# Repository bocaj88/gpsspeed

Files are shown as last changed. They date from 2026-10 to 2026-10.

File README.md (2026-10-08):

# GPSSpeed: a GPS replacement for the PerfectPass paddlewheel

**A small board that reads GPS speed and feeds it to PerfectPass as if it were the paddlewheel.**
Built for, and being tested on, our **2008 MasterCraft X2**. Everything is open: schematic, PCB,
firmware, and the notes on what didn't work along the way.

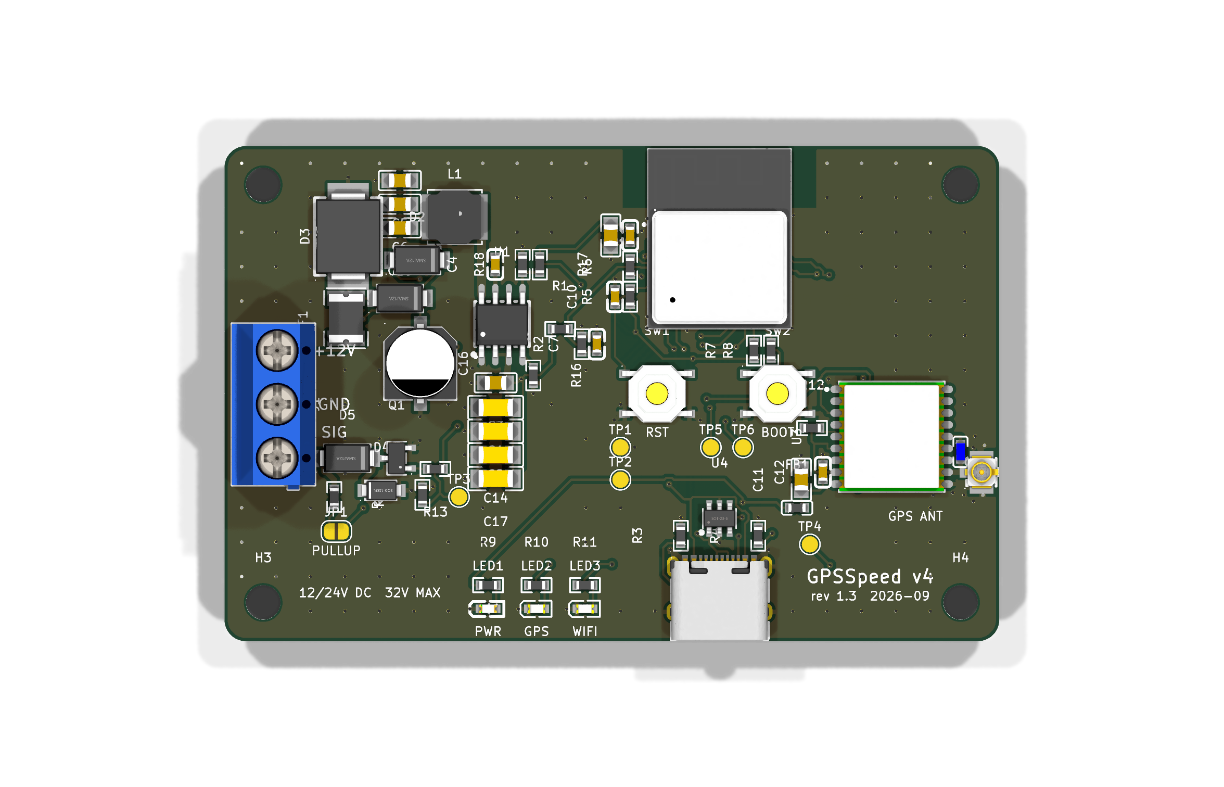
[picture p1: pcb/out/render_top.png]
GPSSpeed v4 rev 1.3


## The problem

**The paddlewheel speed sensor on our X2 went bad, and replacement sensors aren't sold anymore.**
Without it, PerfectPass has no speed to hold, so the speed control on the boat was dead.

PerfectPass holds a tow boat at a set speed by reading the boat's **paddlewheel speed sensor**: a
small wheel under the hull that spins in the water and sends one pulse per fraction of a turn.
On our X2 that sensor is part of an Airmar DST800-style triducer (speed, depth, temperature). It
sends about 20,000 pulses per nautical mile, and PerfectPass turns the pulse rate into speed.

Paddlewheels are the weak link:

- **They foul.** Weed, a fishing line, or a little growth, and the wheel drags or stops. PerfectPass
  then sees the wrong speed (or none) and drives the throttle accordingly.
- **You can't buy a replacement.** The DST800 is now an Airmar *legacy* product. Ours failed, and
  there was nothing to swap in.
- **They're never quite right.** Paddlewheel speed depends on the wheel, the hull, and how clean it
  is, so the dash and the real speed drift apart.

GPS speed doesn't have any of these problems. So the idea is simple: **read speed from GPS, and
generate the same pulse train the paddlewheel would**, on the same wire. PerfectPass doesn't know
the difference, and nothing else on the boat changes.

## How it works

```
 GPS antenna ──► ATGM336H GPS ──► ESP32-C3 ──► protected low-side switch ──► SIGNAL ──► PerfectPass
                 (10 Hz speed)    (pulse rate =      (open-drain, like the
                                   MPH × 4.42 Hz)     paddlewheel's own output)
 Boat 12 V ──► protection + buck ──► 3.3 V
```

- **Output:** a 50 % square wave whose frequency is proportional to speed: **4.42 Hz per MPH** by
  default (about 22 Hz at 5 MPH, 133 Hz at 30 MPH), calibrated from the phone app. It's generated by
  the ESP32's LEDC hardware timer from the 40 MHz crystal, so it's exact (worst-case 0.02 % error)
  and nothing in software can stretch a pulse.
- **No GPS fix yet:** it holds a steady 5 MPH. It never sweeps, because PerfectPass chases a sweep.
- **Lag compensation:** a small predictor projects speed ~0.3 s ahead from GPS acceleration, so
  PerfectPass isn't correcting late and hunting.
- **Phone app, no app install:** for 2 minutes after power-up the board runs its own WiFi network
  (`GPSSpeed-XXXX`, open). Join it and the app pops up: live speed, satellites, a self-test that
  steps through set speeds, a dash calibration table, settings, and **firmware updates over WiFi**.
  Then the radio turns itself off for the rest of the day on the water. It's also at
  `http://gpsspeed.local` while connected.
- **Wiring:** three screw terminals: **+12 V, GND, SIGNAL**.

## Status (October 2026)

| | |
|---|---|
| Hardware | **Rev 1.3**, 5 boards assembled by JLCPCB. Three external EE review rounds (summarized in [docs/04-design-reviews.md](docs/04-design-reviews.md)). |
| Bench-tested | Power, USB, GPS (13–16 satellites, fix indoors), antenna power, battery sense, phone app, **OTA update from an iPhone**. See [docs/05-bring-up.md](docs/05-bring-up.md). |
| Not yet tested | 12 V boat power, the output against a real PerfectPass input, on-water calibration. |
| Firmware | 4.0.8 (`firmware/gpsspeed_v4/bin/`) |

This is a prototype that hasn't run on the water yet. Read [the safety note](#safety) before
connecting it to a boat.

## 4 spare boards

We built 5 and need 1. **The other 4 are available** to anyone who wants to try this on their own
PerfectPass boat. They're fully assembled and flashed: you add an antenna and three wires. Reply in
the forum thread or open an issue on this repo.

## What you need to install one

The board, a GPS antenna, and three wires to the boat. The full list, with where to get each
cable and adapter, is in **[docs/06-wiring-and-cables.md](docs/06-wiring-and-cables.md)**.

## Repo map

| Path | What's there |
|---|---|
| [docs/](docs/) | The research: problem, history, design, reviews, bring-up, wiring, costs |
| [pcb/](pcb/) | KiCad 10 project, generator scripts, JLCPCB order files, renders. Start with [pcb/README.md](pcb/README.md) |
| [firmware/gpsspeed_v4/](firmware/gpsspeed_v4/) | ESP32-C3 firmware (Arduino core 3.3), prebuilt `.bin` images |
| [firmware/test/](firmware/test/) | Host-side tests of the pulse-generation and calibration math |
| [legacy/arduino-uno/](legacy/arduino-uno/) | The earlier Arduino Uno + perfboard builds (v1–v3) |
| [docs/forum-post.md](docs/forum-post.md) | The short version, for forums |

## Safety

This board changes what your speed control believes the boat is doing, and PerfectPass controls the
throttle. Test it at idle and low speed first. Keep a hand on the throttle, and know how to
disengage PerfectPass. Compare the dash against a phone GPS app before trusting it with a rider
behind the boat. Use it at your own risk; see the license.

## License

MIT (see [LICENSE](LICENSE)) for the firmware, scripts, docs and hardware design files.

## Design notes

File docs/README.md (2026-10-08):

# Research and notes

Read in order. Each page stands on its own.

1. [Background: PerfectPass and the paddlewheel](01-background.md): the problem, the signal, the math
2. [History: the Arduino Uno builds](02-history-uno-builds.md): v1 to v3, and the 21 MPH wall
3. [The v4 board](03-v4-board-design.md): design decisions for the ESP32-C3 board
4. [Design reviews](04-design-reviews.md): three EE review rounds and what changed
5. [Bring-up log](05-bring-up.md): first power-up results and firmware fixes
6. [Wiring, cables and adapters](06-wiring-and-cables.md): what you need to install one
7. [Cost and ordering](07-cost-and-ordering.md): what 5 boards cost and how to order them

Also: [TODO](TODO.md) · [Forum post](forum-post.md)

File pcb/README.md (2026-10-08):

# GPSSpeed v4 — ESP32-C3 board

GPS → paddlewheel pulse emulator for PerfectPass, rebuilt as a JLCPCB-assembled
board. Replaces the Uno + perfboard hat.

| | |
|---|---|
| Size | 72 × 46 mm, 2 layers, 1.6 mm, 4× M3 holes |
| Power | **12/24 V DC nominal, 32 V continuous max.** 60 V polyfuse → 1.5 kW bidirectional TVS (±58 V clamp) → 100 V reverse-polarity Schottky → 22 µF/100 V bulk + 4 × 2.2 µF/100 V → LMR38010 buck (80 V operating, 85 V abs max). USB-C on the bench. |
| Brain | ESP32-C3-MINI-1-H4 (WiFi boot window, OTA updates; 105 °C part) |
| GPS | ATGM336H-5N31 (GPS+BeiDou, 10 Hz), u.FL for the existing active antenna |
| Output | ZXMS6004FF self-protected low-side switch (60 V, current limit, thermal shutdown, active clamp) behind a series Schottky (swapped +12 V/GND can't back-drive the dash), 33 V TVS on the drain; survives SIGNAL wired to +12 V; optional pull-up to the input rail via JP1 (ships **open**) |
| Connector | J1 screw terminal: **1 = +12 V, 2 = GND, 3 = SIGNAL** (wires enter from the board edge) |
| LEDs | PWR (red), GPS (green), WIFI (green) |

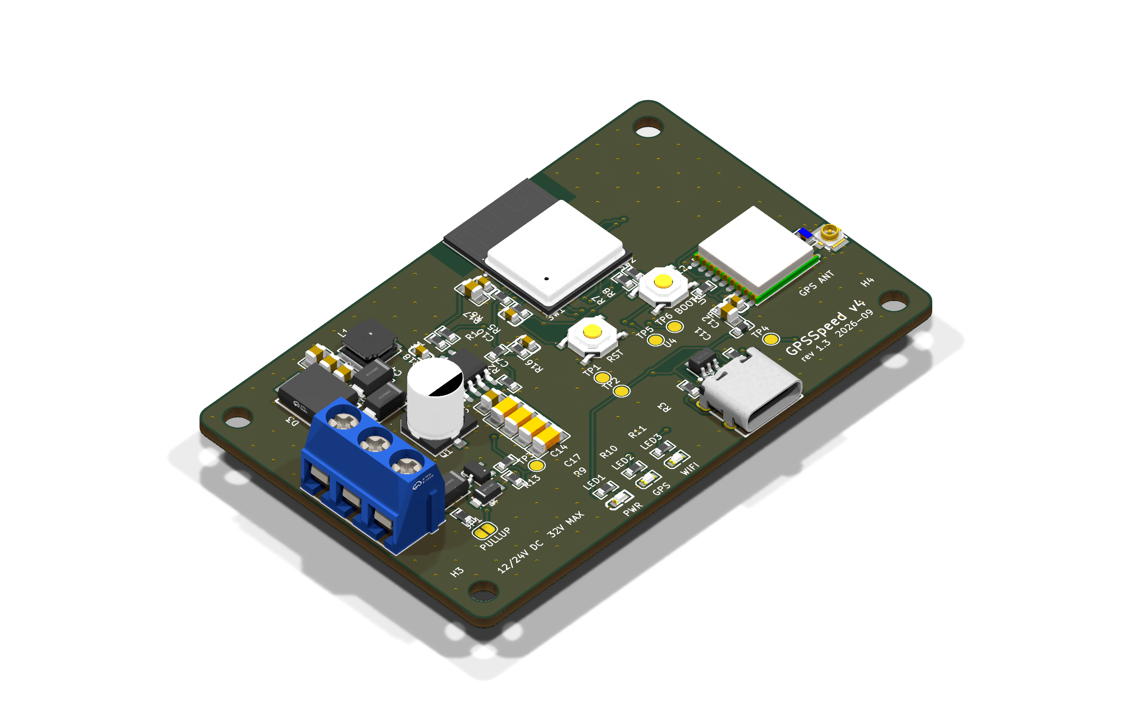
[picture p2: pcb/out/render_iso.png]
top


## Rev 1.3 — third EE review (independent)

| Review item | Change |
|---|---|
| Stop-ship: SIGNAL wired to +12 V shorts the supply through D5 and a bare 2N7002K the first time Q1 turns on | Q1 → **ZXMS6004FF** IntelliFET: current limit 0.7–1.7 A, thermal shutdown with auto-restart, short-circuit protected to V<sub>DS</sub> 36 V. Specified for 3.3 V logic (V<sub>IH</sub> 3 V, 0.6 Ω max at 3 V) |
| D4 (53 V max clamp) vs Q1 (60 V) margin thin | Q1's own active clamp is 60–70 V / 90 mJ, so a spike past D4 is absorbed by design instead of avalanching a bare MOSFET |
| (follows from the above) | SIGNAL_OUT / SIGNAL_DRAIN routed at **0.5 mm** for the 1.7 A fault current |

Bench items from that review (not schematic errors): output-low level with D5 in series against the real
PerfectPass input; USB-only startup at ~4.6 V into the buck. JP1 stays open on 24 V boats.
Q1 switching: ~15 µs on / ~60 µs off. Constant edge delays leave the output frequency unchanged; duty
shifts by ~1 % at 60 MPH.

## Rev 1.2 — second EE review (reviewed the native KiCad files)

| Review item | Change |
|---|---|
| C16 only 63 V against a 58 V clamp | **22 µF / 100 V**, same series and 6.3 × 7.7 can (RV100V22M6X8) |
| Battery-sense pin reaches 3.6 V at the clamp | R1 150k → **220k** (×23): 32 V reads 1.4 V, the 58 V clamp 2.5 V. Firmware **4.0.2** |
| Input ceramics borderline after DC-bias derating | **4th 2.2 µF / 100 V** (C17) |
| 24 V pull-up would forward-bias D5 and make D4 clamp continuously | Q1 → **2N7002K 60 V**, D4 → **SMF33A** (33 V standoff, 53 V clamp < 60 V) |
| Buck exposed pad: one full paste opening, no thermal path | Paste split into **4 windows (60 %)**; **2 tented GND vias** just past the GND-pin end of the pad; pad tied solid into the pour |
| (found while re-checking) | Two u.FL stitching vias overlapped fanout vias (drill-to-drill). Fanout now avoids existing vias, and drill spacing fails the build |

Not changed: L1 stays where it is (SW node ~8.7 mm total; moving it means relocating D2 in the
packed input corner — the reviewer rated it optional for prototypes). D2 stays an SS310: it has
to block up to ~53 V when USB and boat power are both connected, and USB power is bench-only.

## Rev 1.1 — changes from the external EE review

| Review item | Change |
|---|---|
| "12–24 V" label wrong (old TVS conducted ~20 V) | Input re-rated; silk now reads **12/24V DC 32V MAX** |
| TVS + PTC too close to the AP63203's 35 V abs max | Buck → **LMR38010** (80 V / 85 V abs), TVS → **SMCJ36CA** 1.5 kW bidirectional, PTC → 60 V, D1/D2 → **SS310** 100 V, input ceramics → 100 V, + **47 µF/63 V** bulk |
| L2's 1.2 GHz SRF below GPS L1 | L2 → **Murata LQW18AN27NG** wirewound, SRF 3.7 GHz |
| SIGNAL back-drive on reverse wiring | **D5 SS310 in series** at J1 pin 3 (chosen over a resistor so a stiff head-unit pull-up can't break the low level; adds ~0.3 V) |
| Open via-in-pad under the ESP32 | Removed; also stripped 4 open vias JLC's footprint put in the buck's exposed pad |
| Buck loop / u.FL grounding | Hand-routed C3–VIN–GND loop (~2 mm), SW straight into L1, FB on the quiet side; 8 stitching vias around the u.FL |

Not changed (reviewed and accepted): USB diode-OR (verify startup during WiFi TX on the bench),
reboot on very deep crank dips (firmware ignores brownouts for rollback), SMF15A on the drain
(24.4 V clamp < Q1's 30 V).

**Potting:** keep resin off the ESP32 antenna end (top edge) — resin detunes the PCB antenna.
Leave an air pocket there, or pot only the lower two-thirds of the board.

## What fixes the old problems

- **21 MPH cliff:** gone. The square wave comes from the LEDC hardware peripheral off
  the 40 MHz crystal; no software can stretch it. Measured on the real firmware code:
  worst frequency error **0.02 %** across 1–60 MPH (the Uno drifted up to 2.5 % fast
  at 30 MPH from its 128 µs rounding).
- **One serial port:** the GPS has its own hardware UART; USB-C serial is always free.
- **Tuning at the dock with a laptop:** everything is edited from your phone.

## Files

```
pcb/
  gpsspeed.kicad_pro / .kicad_sch / .kicad_pcb   open in KiCad 10
  gpsspeed.kicad_dru      two scoped DRC exceptions (explained inside)
  lib/                    exact JLC footprints/symbols/3D (easyeda2kicad)
  gen/                    the generators -- design.py is the netlist source of truth
  out/jlcpcb/             gerbers.zip, bom_jlcpcb.csv, cpl_jlcpcb.csv   <- upload these
  out/                    schematic PDF, assembly PDF, STEP, renders
firmware/gpsspeed_v4/     ESP32-C3 firmware; bin/ has prebuilt images
firmware/test/            host-side tests of the pulse + calibration code
```

## Ordering at JLCPCB

1. **PCB:** upload `out/jlcpcb/gerbers.zip`. Defaults are right: 2 layers, 1.6 mm,
   HASL lead-free, green. Qty 5 (the minimum).
2. **PCB Assembly:** on, *Standard*, *Top side*, qty **5**. (Economic won't take
   the ESP32 module -- JLC flags every ESP32-C3-MINI-1 "Standard PCBA only".)
3. Upload `bom_jlcpcb.csv` and `cpl_jlcpcb.csv`.
4. In the **parts review**, every line should match an LCSC number. J1 (screw
   terminal) is through-hole; if Economic won't place it, untick it and solder its
   3 pins by hand.
5. In the **placement preview**, check polarity/pin-1 on: D1–D5, C16 (+), LED1–3, U1–U4, Q1,
   J2, J3. Footprints came from JLC's own library, so rotations should already
   match, but this is the one step a human should eyeball.

Rev 1.1 quote (2026-09-26), for reference: 5 assembled boards $162.84, + UPS ~$37 + US
customs duty ~$61 (JLC collects it up front with DDP shipping) − $10 coupon ≈ $251.

## Bring-up

1. **Before power:** meter +12 V to GND on J1 — must not beep.
2. **USB-C only first.** PWR LED on, TP2 = 3.3 V.
3. Flash once over USB-C:
   ```
   esptool.py --chip esp32c3 write_flash 0x0 firmware/gpsspeed_v4/bin/gpsspeed_v4-4.0.8-usb-full.bin
   ```
   (or `arduino-cli upload` — build command is in `gpsspeed_v4.ino`). If it won't
   connect, hold **BOOT**, tap **RST**, release BOOT.
4. Serial monitor at 115200: expect `chars:` climbing and `ant:OK` once the antenna
   is on. `ant:OPEN` = antenna not connected / passive; `ant:SHORT` = cable fault.
5. Plug in the antenna, go outside, wait for the GPS LED to go solid.
6. **Then** wire the boat: +12 V, GND, SIGNAL to the paddlewheel signal line.

## Using it on the boat

- Power on → join WiFi **`GPSSpeed-XXXX`** (open, no password; XXXX is fixed per board) → the page pops up, tap **Done** → later just open **http://gpsspeed.local**
  (Safari; a captive-portal sheet may open on its own).
- The access point lives **2 minutes** after power-on, extends while your phone is
  connected, then turns the radio off. To get back in: cycle power.
- **Calibrate once:** tap *Self-test*, and at each step type what the dash shows into
  *Dash shows* → *Save point*. One pass gets the dash within ~0.01 MPH at the
  calibrated speeds (tested against a simulated nonlinear dash).
- While GPS is searching the output holds a steady **5 MPH** (never sweeps).
- **Firmware updates:** *Firmware → Upload* the `-ota.bin`. A bad build that
  crash-loops rolls back to the previous one automatically; brownouts from engine
  cranking do not count as crashes.

## Things I could not verify without hardware

- **CASIC config commands** (`$PCAS01/02/03`) follow ZhongKe's documented format. If
  the module ignores one, the firmware still works at its defaults (9600 baud, 1 Hz)
  — the web UI shows the actual baud/rate it achieved.
- **Default Hz/MPH is 4.42**, the Uno's *effective* constant at 15–26 MPH. Expect to
  run the self-test once.
- **Active antenna assumed** (GT-U7 kits ship with one). For a passive antenna,
  remove L2.
- **Wiring polarity:** the board survives +12 V/GND swapped (D5 keeps the swap from
  back-driving the dash input) and SIGNAL wired to +12 V (Q1 current-limits and thermal-cycles).
  Still meter it before powering.
- **JP1 on 24 V boats:** leave it open. Bridged at 28.8 V, R15 (0603) runs near its 0.1 W
  rating; the dash's own pull-up is the normal case anyway.

## Regenerating

```
cd pcb/gen
~/Applications/KiCad/KiCad.app/Contents/Frameworks/Python.framework/Versions/3.9/bin/python3 gen_sch.py
~/Applications/KiCad/KiCad.app/Contents/Frameworks/Python.framework/Versions/3.9/bin/python3 build.py   # place, route, pour, DRC
python3 gen_outputs.py                                                                                  # JLC files
```
`build.py` needs Freerouting (`~/Applications/freerouting`) and Java ≥ 25
(`brew install openjdk`). Edit `design.py` for circuit changes, `gen_pcb.py` for
placement.

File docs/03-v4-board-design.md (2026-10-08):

# 3. The v4 board (ESP32-C3)

The full hardware write-up, including the bring-up checklist, is [pcb/README.md](../pcb/README.md).
This page covers the main decisions and the reasons behind them.

| | |
|---|---|
| Size | 72 × 46 mm, 2 layers, 4 × M3 holes |
| MCU | ESP32-C3-MINI-1-H4 (WiFi, native USB, 105 °C rated) |
| GPS | ATGM336H-5N31 (GPS + BeiDou, 10 Hz), u.FL for an external **active** antenna |
| Power in | 12/24 V nominal, **32 V continuous max**; USB-C on the bench |
| Output | ZXMS6004FF protected low-side switch behind a series Schottky. Open-drain, like the paddlewheel |
| Connector | J1 screw terminal: **1 = +12 V, 2 = GND, 3 = SIGNAL** |
| LEDs | PWR (red), GPS (green), WIFI (green) |

## Decisions

**ESP32-C3 instead of another AVR or an RP2040.** WiFi comes free on the chip, and iOS can't use Web
Bluetooth, so a web page served by the board beats BLE plus a custom app. The C3 also has a
separate hardware UART for the GPS and native USB for flashing and logs. That solves the Uno's
one-serial-port problem outright.

**Hardware pulse generation.** The output comes from the LEDC peripheral, clocked from the 40 MHz
crystal. The Arduino `ledc` API only accepts whole hertz (0.23 MPH steps), so the firmware writes
the fractional clock divider directly (`div = 625000 / f`). Host tests show **≤ 0.02 % frequency
error** from 1 to 60 MPH.

**GPS module soldered to the board.** The ATGM336H is configured with CASIC `$PCAS` commands (it
doesn't speak u-blox UBX). The firmware auto-detects the baud rate and switches the module to
115200 baud and 10 Hz. That was confirmed on the first board.

**Power: built for a hostile boat harness.**
60 V polyfuse → 1.5 kW bidirectional TVS (SMCJ36CA, ≈ ±58 V clamp) → 100 V reverse-polarity Schottky
→ 22 µF/100 V bulk + 4 × 2.2 µF/100 V → TI LMR38010 buck (80 V operating, 85 V abs max) → 3.3 V.
USB-C also feeds the buck through a second diode, so the board runs from either source.

**Output stage: survives miswiring.**
- A **ZXMS6004FF IntelliFET** (60 V, current limit 0.7–1.7 A, thermal shutdown, 60–70 V active
  clamp) pulls SIGNAL low. If SIGNAL is wired to +12 V by mistake, it current-limits and cycles
  instead of burning out.
- A **series Schottky (D5)** stops a swapped +12 V/GND from back-driving the dash input through the
  switch. It adds about 0.3 V to the low level, much like a real Hall-effect sensor.
- A **33 V TVS** clamps the drain, so a 24 V pull-up is fine.
- An optional on-board **4.7 k pull-up** (JP1, ships open) covers dashes that don't supply one.

**WiFi boot window.** The access point runs for 2 minutes after power-up, extends while a phone is
connected, then shuts off. Firmware updates over WiFi verify the image, and a build that
crash-loops rolls back automatically. Brownout resets from engine cranking don't count as crashes.

**Potting.** Keep resin off the ESP32 antenna end (top edge), or pot only the lower two-thirds:
resin detunes the PCB antenna.

## How the board was generated

The schematic and PCB come from Python scripts. `pcb/gen/design.py` is the single netlist source.
Footprints and 3D models are pulled from JLC's own library (easyeda2kicad), routing is done by
Freerouting, then ground pours and stitching are added. Every build must pass KiCad DRC, ERC and
schematic parity, and drill spacing is a hard error. See *Regenerating* in
[pcb/README.md](../pcb/README.md).

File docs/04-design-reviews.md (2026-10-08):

# 4. Design reviews

The board went through three external electrical-engineering reviews before it was ordered. Each
round's findings and what changed are below; the per-revision tables are also in
[pcb/README.md](../pcb/README.md).

## Round 1: rev 1.0 → 1.1

Reviewer's verdict: fine on a bench supply, but not ready for an unsuppressed marine electrical
system.

| Finding | Change |
|---|---|
| The "12–24 V" label was wrong: the old SMBJ18A TVS starts conducting around 20 V | Input re-rated; silkscreen now **12/24V DC 32V MAX** |
| The TVS and PTC sat too close to the AP63203 buck's 35 V absolute max | Buck → **LMR38010** (80 V); TVS → **SMCJ36CA** 1.5 kW bidirectional; 60 V PTC; 100 V diodes and input ceramics; bulk capacitor added |
| L2 (the GPS antenna bias choke) self-resonated at 1.2 GHz, below GPS L1 (1.575 GHz) | Murata **LQW18AN27NG** wirewound, self-resonant at 3.7 GHz |
| Swapped +12 V/GND could back-drive the dash through the MOSFET's body diode | **Series Schottky D5** on SIGNAL |
| Open via-in-pad under the ESP32 | Removed |
| Buck loop and u.FL grounding | Hand-routed buck input loop; 8 stitching vias around the u.FL |

## Round 2: rev 1.1 → 1.2 (reviewer had the native KiCad files)

| Finding | Change |
|---|---|
| C16 rated only 63 V against a 58 V clamp | **22 µF / 100 V** (same can size) |
| The battery-sense ADC pin reached ~3.6 V at the clamp | 150 k → **220 k** (×23 divider) |
| Input capacitance borderline after DC-bias derating | **Fourth 2.2 µF / 100 V** |
| A 24 V pull-up would forward-bias D5 and make D4 clamp continuously | Q1 → **60 V** part, D4 → **SMF33A** |
| One full-size paste opening on the buck's exposed pad (risk of floating the part) | Paste split into **4 windows (60 %)**, 2 tented ground vias beside the pad, pad tied solid into the ground pour |
| *Found by us while re-checking* | Two stitching and fanout vias overlapped near the u.FL. The placement script was fixed, and drill spacing now fails the build |

Not changed: L1 stays where it is. The reviewer called moving it closer "desirable, not
essential", and doing so meant relocating D2 in the crowded input corner.

## Round 3: rev 1.2 → 1.3 (independent reviewer, fresh eyes)

| Finding | Change |
|---|---|
| **Stop-ship:** if SIGNAL is wired to +12 V, the first time Q1 turns on it shorts the supply through D5 and a bare 2N7002K | Q1 → **ZXMS6004FF** protected low-side switch (current limit, thermal shutdown). SIGNAL traces widened to 0.5 mm for the fault current |
| D4/Q1 clamp margin thin (53 V clamp vs 60 V switch) | The ZXMS6004FF has its own 60–70 V active clamp rated for 90 mJ |
| Bench-test item: USB-only startup at ~4.6 V into the buck | **Passed** on the first board, including WiFi transmitting |
| Bench-test item: the output-low level with D5 in series against the real PerfectPass input | Not yet tested |
| Operational: JP1 pull-up on 24 V boats overheats R15 | Documented: leave JP1 open on 24 V |

The reviewer reported no reversed pinouts, power-topology errors, ESP32 strapping mistakes, or
GPS/USB wiring problems.

## Placement check at JLC

JLC's engineers asked us to confirm the polarity of the SS310 diodes (D1, D2, D5). The question came
up because that part's library footprint puts the pin-1 dot on the anode, while most diodes put it
on the cathode. Our cathode bands matched the circuit. JLC also revised the GPS module's (U3) entry in
their pick-and-place data. They didn't say how, but the final placement matched the design.

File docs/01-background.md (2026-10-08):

# 1. Background: PerfectPass and the paddlewheel

## The boat

A **2008 MasterCraft X2** with PerfectPass speed control. Speed comes from the hull's paddlewheel
sensor, part of an Airmar DST800-type triducer (paddlewheel speed + depth + water temperature in one
through-hull).

- Airmar DST800 (now a legacy product): <https://www.airmar.com/Catalog/Legacy-Products/DST800P>
- MasterCraft TeamTalk thread with the triducer wiring diagram:
  <https://teamtalk.mastercraft.com/forum/general-mastercraft-topics/general-discussion/2740901-vdig-touch-screen-replacement>
- DST800 wiring discussion (Sailing Anarchy): <https://forums.sailinganarchy.com/threads/dst800-wiring-to-0183-help.234318/>

## What PerfectPass sees

The paddlewheel output is a pulse train: each pulse is a fixed slice of a turn of the wheel, so
**pulse frequency is proportional to speed**. The output is open-collector: the sensor pulls the
signal line to ground and the gauge or PerfectPass side supplies the pull-up.

The DST800 is specified at about **20,000 pulses per nautical mile**:

```
1 MPH = 0.869 knots = 0.869 nm/hour
0.869 × 20,000 pulses = 17,380 pulses/hour = 4.83 pulses/second
=> about 4.83 Hz per MPH
```

In practice the constant that made our dash read correctly was **about 4.42 Hz per MPH**.
PerfectPass applies its own calibration, and our first emulator's timing also shifted the number
(see [history](02-history-uno-builds.md)). So the firmware treats the constant as a setting:
`Hz/MPH` defaults to 4.42, and the app's calibration table corrects it per boat.

## Why we built this

Our paddlewheel failed, and replacement DST800 sensors aren't sold anymore. Without a speed signal,
PerfectPass doesn't work at all.

## The fix in one sentence

Generate that same open-collector pulse train from GPS speed, on the same signal wire, and
PerfectPass can't tell the difference.

## Requirements we designed to

| Requirement | Why |
|---|---|
| Three screw terminals: +12 V, GND, SIGNAL | Install without new harnesses |
| Survive 12/24 V boat power, transients, reverse wiring, SIGNAL miswired to +12 V | It lives on a boat's electrical system |
| Exact, jitter-free output frequency | PerfectPass integrates it; jitter becomes throttle hunting |
| Hold a steady value with no GPS fix, never sweep | A sweeping speed makes PerfectPass chase it |
| Low lag | PerfectPass is a control loop; a late speed makes it oscillate |
| Configure and update from a phone, no laptop | The board ends up potted in resin behind the dash |
| Radio off on the water | Keep RF away from the GPS and the boat's electronics |
| Under ~$150 for the electronics | It has to beat buying a new paddlewheel |

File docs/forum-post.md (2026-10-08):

# Forum post (MasterCraft TeamTalk)

**Suggested title:** Open-source GPS replacement for the PerfectPass paddlewheel (2008 X2), 4 spare boards

---

The paddlewheel on our 2008 X2 went bad, and replacement sensors aren't sold anymore (the DST800
it's part of is an Airmar legacy part). No paddlewheel means no PerfectPass. So we built a small
board that reads **GPS speed** and sends PerfectPass the same pulse signal the paddlewheel would.
It goes on the same wire, so nothing else on the boat changes.

**What it is**
- 72 × 46 mm board: ESP32-C3 + 10 Hz GPS, screw terminals for **+12 V / GND / SIGNAL**
- Exact hardware-timed output (≤ 0.02 % error), holds a steady 5 MPH until GPS locks, with lag
  compensation so PerfectPass doesn't hunt
- **Phone app with no app install:** for 2 minutes after power-up it runs its own WiFi. Join it and
  the page pops up with live speed, a self-test, dash calibration, settings, and **firmware updates
  over WiFi**. Then the radio turns off.
- Protected for boat power: 12/24 V, reverse polarity, ±58 V transients, and SIGNAL accidentally
  wired to +12 V
- Three rounds of outside EE review before we ordered

**Status:** 5 boards built (JLCPCB). Bench-tested: GPS locks indoors in seconds, the phone app
works, and over-the-air updates work. **On-water testing in our X2 is next.** We'll post results.

**Everything is open source** (schematic, PCB, firmware, and every dead end along the way):
👉 **GitHub: https://github.com/bocaj88/gpsspeed**
- Wiring + where to get the cables/adapters: https://github.com/bocaj88/gpsspeed/blob/main/docs/06-wiring-and-cables.md
- Full write-up, starting with the problem: https://github.com/bocaj88/gpsspeed#readme

**4 spare boards:** we built 5 and need 1. If you have a PerfectPass boat and want to try one,
reply here or DM me. They come assembled and flashed; you add a GPS antenna and three wires.

Questions or ideas welcome, especially from anyone who knows the PerfectPass input side well.

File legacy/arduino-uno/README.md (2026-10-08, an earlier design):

# Arduino Uno builds (v1–v3)

The first versions: an Arduino Uno with a perfboard hat (GPS module, IRLZ44N MOSFET, screw terminal).
Kept for reference; the story and lessons are in [docs/02-history-uno-builds.md](../../docs/02-history-uno-builds.md).

| Folder | What it is |
|---|---|
| `v1-variants/` | First working sketches; one copy per serial wiring (the one-UART problem) |
| `Integration/` | Integration experiments (2024–2025) |
| `v2/` | Consolidated sketch: 10 Hz GPS, predictor, self-test, steady 5 MPH with no fix |
| `v3/` | Timer1 hardware output on pin 9 (needs one jumper on the hat; see the header) |

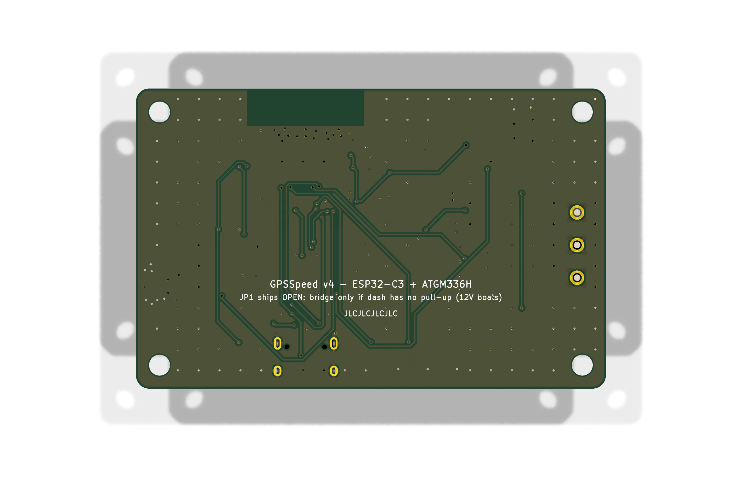
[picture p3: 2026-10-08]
pcb/out/render_bottom.png

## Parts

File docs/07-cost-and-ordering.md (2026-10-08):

# 7. Cost and ordering

## What 5 assembled boards cost (JLCPCB, rev 1.3, shipped to New York, Sept 2026)

| Item | USD |
|---|---|
| PCB (5 pcs, 2-layer, lead-free HASL) | 5.20 |
| Standard PCBA (setup, stencil, 35 parts, feeder fees, X-ray, placement check) | 160.58 |
| UPS Express Saver, duties paid by JLC (DDP) | 37.23 |
| US customs duty + fee (China tariff) | 59.02 |
| New-user SMT coupon | −10.00 |
| NY sales tax | 15.44 |
| **Total** | **267.47** |

That's about **$53 per board**, delivered. The components themselves are about $12 a board. Most of
the cost is fixed per order: Standard PCBA setup ($25.75) and $3 extended-part fees ($52.70), which
shrink per board at higher quantities. The tariff is about 35 % of the goods value and applies to any
China-based assembler.

## Why "Standard" PCBA

JLC only places the ESP32-C3-MINI-1 module under Standard assembly ("Standard PCBA only"), which
adds edge rails and a higher setup fee than Economic. The module is ordered as the **-H4** variant
(C2934569, 105 °C rated); same footprint and flash as the -N4.

## Ordering it yourself

1. Upload `pcb/out/jlcpcb/gerbers.zip`. Defaults are fine: 2 layers, 1.6 mm, green. We used
   LeadFree HASL.
2. PCB Assembly: **Standard**, top side, edge rails added by JLC, **Confirm Parts Placement: Yes**.
3. Upload `pcb/out/jlcpcb/bom_jlcpcb.csv` and `cpl_jlcpcb.csv`. All 35 lines should match.
4. Check polarity in the preview: D1–D5, C16 (+), LEDs, U1–U4, Q1. The SS310's pin-1 dot is on its
   **anode**. Its cathode band should be on the side with the silkscreen bar.
5. Customs description: *Research/Education/DIY → Programmable Controller (HS 853890)*.

Expect the parts-placement confirmation request within a few days, and answer it quickly so the
order doesn't sit.

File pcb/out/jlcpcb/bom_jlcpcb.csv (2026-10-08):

Comment | Designator | Footprint | LCSC Part #
12V / GND / SIG | J1 | CONN-TH_3P-P5.00_KF301-5.0-3P | C474882
500mA PTC 60V | F1 | F1812 | C19078719
SMCJ36CA 1.5kW | D3 | SMC_L6.9-W5.9-LS7.9-BI | C19077609
SS310 rev-pol | D1,D2,D5 | SMA_L4.3-W2.6-LS5.0-FD | C7420364
22uF 100V | C16 | CAP-SMD_BD6.3-L6.6-W6.6-LS7.4-FD | C48971012
2.2uF 100V | C1,C2,C14,C17 | C1206 | C170101
100nF 100V | C3 | C0805 | C28233
LMR38010SDDAR | U1 | SOIC-8_L4.9-W3.9-P1.27-LS6.0-BL-EP-1 | C5219310
100nF | C4,C7,C9,C12 | C0603 | C14663
51k | R16 | R0603 | C23196
47k | R17 | R0603 | C25819
20k | R18 | R0603 | C4184
15uH 2.2A | L1 | IND-SMD_L5.0-W5.0 | C167969
22uF | C5,C6,C15 | C0805 | C45783
220k | R1 | R0603 | C22961
10k | R2,R5,R6,R7,R8,R12 | R0603 | C25804
USB-C | J3 | USB-C-SMD_TYPE-C-16PIN-2MD-073 | C2765186
5.1k | R3,R4 | R0603 | C23186
USBLC6-2SC6 | U4 | SOT-23-6_L2.9-W1.6-P0.95-LS2.8-BL | C2687116
ESP32-C3-MINI-1-H4 | U2 | WIFIM-SMD_ESP32-C3-MINI-1 | C2934569
10uF | C8,C11 | C0805 | C15850
1uF | C10 | C0603 | C15849
RESET | SW1,SW2 | SW-SMD_4P-L5.1-W5.1-P3.70-LS6.5-TL_H1.5 | C318884
1k | R9 | R0603 | C21190
PWR red | LED1 | LED-SMD_L1.6-W0.8-R-RD | C2286
100R | R10,R11,R13 | R0603 | C22775
GPS FIX green | LED2,LED3 | LED0603-RD | C12624
600R@100MHz | FB1 | L0603 | C1002
ATGM336H-5N31 | U3 | GPSM-SMD_ATGM336H-TR | C90770
27nH LQW18AN | L2 | IND-SMD_L1.6-W0.8-1 | C148128
u.FL GPS ANT | J2 | RF-SMD_FRF05002-JSS103M | C88374
100k | R14 | R0603 | C25803
ZXMS6004FF 60V prot | Q1 | SOT-23-3_L2.9-W1.6-P1.90-LS2.8-BR | C95063
SMF33A TVS | D4 | SOD-123FL_L2.7-W1.8-LS3.8-RD | C726914
4.7k | R15 | R0603 | C23162

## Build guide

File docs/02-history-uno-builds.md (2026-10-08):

# 2. History: the Arduino Uno builds (v1–v3)

The first versions were an Arduino Uno with a perfboard "hat": a GPS module, a logic-level MOSFET
(IRLZ44N) pulling the signal line to ground, and a 3-way screw terminal for +12 V / GND / SIGNAL.
GPS module: a MakerFocus GT-U7 (NEO-6M compatible), <https://www.amazon.com/dp/B07P8YMVNT>.
The code is in [`legacy/arduino-uno/`](../legacy/arduino-uno/).

They worked well enough to prove the idea on the boat. They also ran into every problem the v4
board was designed around.

## v1: proof of concept

- GPS speed read with TinyGPS++, and a square wave generated by toggling a pin in `loop()`.
- **Never use `delay()`.** The pulse is scheduled by comparing `micros()` against the next toggle
  time, so reading the GPS doesn't stall the output.
- Speed could also be typed in over USB serial, which is how the first Hz-per-MPH constant was
  tuned against the dash.

## The one-serial-port problem

The Uno has one hardware UART, and the GPS and the USB serial monitor both want it.

- **GPS on SoftwareSerial:** the serial monitor works, but bit-banging the GPS at 9600 baud keeps
  interrupting the pulse loop. **Above ~21 MPH the pulses stretched and the dash jumped to ~30 MPH.**
  This was the wall that stopped the Uno approach.
- **GPS on hardware serial:** the pulses are clean at speed, but there's no serial monitor, and you
  have to unplug the GPS to upload. That's how many copies of the sketch came to exist (`v1_serial`,
  `v1_sw_serial`, …).

## v2: consolidated

- One sketch, with a compile-time switch for which serial the GPS uses.
- GPS raised from 1 Hz to **10 Hz** (UBX commands to the NEO-6M), plus a **lag predictor**. PerfectPass
  was oscillating because the speed it saw lagged the real speed.
- **Self-test mode:** holds 0/10/15/20/22/24/26/30 MPH for 30 s each, so the dash reading can be
  written down at each step and the constant fitted.
- The original "sweep the speedo while waiting for GPS lock" idea was **removed**: PerfectPass tried
  to follow the sweep. v2 pins the output to **5 MPH** until there's a fix.

## v3: Timer1

- Moves the output to **pin 9 (OC1A)** so the Uno's Timer1 hardware toggles the pin. The pulse no
  longer depends on how busy `loop()` is.
- The hat only breaks out pin 6, so v3 needs one jumper wire. It sets pin 6 to a high-impedance
  input, so leaving the old wire in place can't make two outputs fight each other.

## Why the Uno timing read ~4.42 Hz/MPH

The v1/v2 pulse code rounded every half-period **down** to a multiple of 128 µs. That made the real
output 1–2.5 % fast, increasingly so at higher speed. Tuned against the dash, the effective constant
across 15–26 MPH came out around **4.42 Hz/MPH**. The v4 board generates the frequency exactly, so
it starts from the Uno's *effective* value to read the same on the dash.

## Lessons that shaped v4

1. **Don't generate the pulse in software.** Use a hardware timer clocked from a crystal.
2. **The GPS gets its own UART**, and USB serial stays free for debugging.
3. **Power and wiring faults are real.** In this project a VCC-to-GND short killed a perfboard, a
   GPS module, and one Uno's USB chip. v4 has reverse-polarity, transient, and miswire protection.
4. **No laptop at the dock.** Settings and updates have to come from a phone.
5. **Never sweep the output.** Hold a steady value when there's no data.

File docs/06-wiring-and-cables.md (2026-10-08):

# 6. Wiring, cables and adapters

Everything you need besides the board itself.

> **⚠ To be completed by Jake:** the boat-side connectors and adapters we used on the X2 (rows
> marked **TBD**). Each one needs the exact part and where to buy it.

## Shopping list

| # | Item | What to get | Notes |
|---|---|---|---|
| 1 | GPS antenna | An **active** GPS antenna (3.3 V) with a **u.FL / IPEX1** plug. The antenna that comes with the MakerFocus GT-U7 kit works: <https://www.amazon.com/dp/B07P8YMVNT> | The board powers the antenna through the u.FL. Mount it flat with a clear view of the sky. Fiberglass, plastic and canvas overhead are fine; metal is not |
| 2 | SMA adapter (only if your antenna has an SMA plug) | **SMA female → u.FL (IPEX1) pigtail**, ~10–15 cm | Most marine and "puck" GPS antennas are SMA |
| 3 | Boat power + ground | **TBD**: connector/adapter we used on the X2 | Use **switched** +12 V so the board powers on with the boat. The input is protected for 12/24 V systems, 32 V continuous max |
| 4 | Speed signal | **TBD**: the plug that mates with the paddlewheel / PerfectPass speed connector, so the harness doesn't have to be cut | SIGNAL replaces the paddlewheel's signal wire into PerfectPass. Leave the paddlewheel's own signal wire disconnected |
| 5 | Wire | 18–20 AWG marine (tinned) wire, three colors | The screw terminal (KF301, 5.0 mm pitch) takes 14–22 AWG |
| 6 | USB-C cable | Any **data-capable** USB-C cable | Only needed for the first flash or recovery. After that, updates go over WiFi |

## Screw terminal J1

Looking at the board with the terminal on the left, top to bottom:

| Pin | Label | Connect to |
|---|---|---|
| 1 | **+12V** | Switched +12 V (12/24 V nominal, 32 V max) |
| 2 | **GND** | Boat ground |
| 3 | **SIG** | The PerfectPass paddlewheel/speed input |

## Before you power it on the boat

1. **Meter it.** In beep mode, +12V to GND must not beep continuously (a brief chirp is the
   capacitors charging).
2. **Power it from USB first**, and check the app sees a GPS fix.
3. **Wire it**, power up, and check the app: GPS fix, `vin` around your battery voltage.
4. **Self-test** (in the app) steps through 0 / 10 / 15 / 20 / 22 / 24 / 26 / 30 MPH. At each step,
   type in what the dash reads and save it. That calibrates the board to your boat.

## The JP1 pull-up

A real paddlewheel is open-collector: the dash or PerfectPass supplies the pull-up. JP1 ships
**open**. Only bridge it if your dash doesn't pull SIGNAL up on its own (the app would show pulses
but the dash would read 0). **Never bridge JP1 on a 24 V boat.**

## Wiring mistakes the board survives

- +12 V and GND swapped (reverse-polarity diode; D5 keeps the dash input safe).
- SIGNAL wired to +12 V (the output switch current-limits and cycles).
- Transients up to about ±58 V at full surge current (1.5 kW TVS).

None of these is a reason to skip the meter check.

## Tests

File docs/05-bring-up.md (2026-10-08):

# 5. Bring-up log

## 2026-10-08: board 1 (rev 1.3), USB power

| Check | Result |
|---|---|
| USB-C to a Mac | Enumerates as Espressif "USB JTAG_serial debug unit" (VID 0x303A) → `/dev/cu.usbmodem*` |
| `esptool flash_id` | ESP32-C3, 40 MHz crystal, 4 MB flash |
| Flash firmware over USB | OK |
| Boot | `GPSSpeed v4.0.x … GPS:115200 baud @ 10 Hz`, so the CASIC configuration commands work |
| WiFi on USB power alone (the review's "USB-only startup" item) | **OK**: the access point comes up and serves pages on USB power |
| Battery sense on USB | `vin: 4.8` (USB 5 V minus the diode drop). The 220 k / 10 k divider reads correctly |
| No antenna | `ant:OPEN`; output holds 5 MPH (22.1 Hz) |
| Active antenna on the u.FL | `ant:OK`. **Fix indoors in seconds, 13–16 satellites** |
| At rest with a fix | Output drops to 0 Hz below 0.6 MPH (the dash would read 0) |
| Phone (iPhone) | Joins the open `GPSSpeed-XXXX` network, the app pops up, **Done** saves the network, `gpsspeed.local` works |
| **Over-the-air update from the iPhone** | **OK**: uploaded 4.0.7, verified, rebooted into it |

### Firmware fixes found during bring-up

- **4.0.4:** the WiFi name changed every boot (`GPSSpeed-0060`, then `-0000`). `WiFi.macAddress()`
  returns junk before the radio starts, so phones never found a saved network again. The name now
  comes from the factory MAC in eFuse, so it's permanent per board.
- **4.0.3 / 4.0.5:** the iOS captive-portal flow. At first the board redirected every iOS "is there
  internet?" check to the app, so iOS never finished joining and never saved the network.
  Answering "online" after the page loads fixed the joining. But iOS's *background* check follows
  the redirect too, and doesn't run JavaScript, so the pop-up then showed "Success". The board now
  waits for the page's own JavaScript to check in (`/api/hello`) before answering "online". Only
  known OS check URLs ever get "Success".
- **4.0.6:** the WiFi is open by default; a password can be set from the app.
- **4.0.3:** `http://gpsspeed.local` via mDNS.

## Still to do

See [TODO.md](TODO.md).

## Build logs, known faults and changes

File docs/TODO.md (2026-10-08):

# TODO

## Bench (before the boat)

- [ ] Power board 1 from **12 V** through the screw terminal (bench supply with a ~200 mA current limit, or a battery). Check `vin` and that it boots and the WiFi works.
- [ ] **Check the SIGNAL output**: run Self-test in the app and confirm SIG pulses at the commanded rate (a meter's Hz mode, or the old Uno setup). Check the low level with D5 in series.
- [ ] Flash boards 2–5 over USB (one time each, ~30 s). After that they update over WiFi.
- [ ] Try "Open in browser" from inside the iOS pop-up (does it open Safari, or load inside the pop-up?).

## Boat (2008 MasterCraft X2)

- [ ] Wire +12 V (switched), GND, SIGNAL. Leave the paddlewheel's signal wire disconnected.
- [ ] Mount the antenna flat, with sky view.
- [ ] Idle and low speed first, with a hand on the throttle. Compare the dash against a phone GPS app.
- [ ] Run Self-test and save a calibration point at each step.
- [ ] Tune PerfectPass behavior: predictor lead/smoothing if it hunts.
- [ ] Pot the board (keep resin off the ESP32 antenna end).

## Repo / community

- [ ] Fill in the X2 boat-side connectors and adapters in [06-wiring-and-cables.md](06-wiring-and-cables.md).
- [ ] Add photos of the installed board.
- [ ] Post on **MasterCraft TeamTalk** (primary forum: <https://teamtalk.mastercraft.com>) using [forum-post.md](forum-post.md), then other PerfectPass/wakeboard boat forums.
- [ ] Find homes for the 4 spare boards.
- [ ] Update this repo with on-water results.

## Possible next revision (not needed for the prototypes)

- Move L1 closer to U1 (shorter switch node, less EMI).
- Lower-drop USB OR-ing (bench convenience only).

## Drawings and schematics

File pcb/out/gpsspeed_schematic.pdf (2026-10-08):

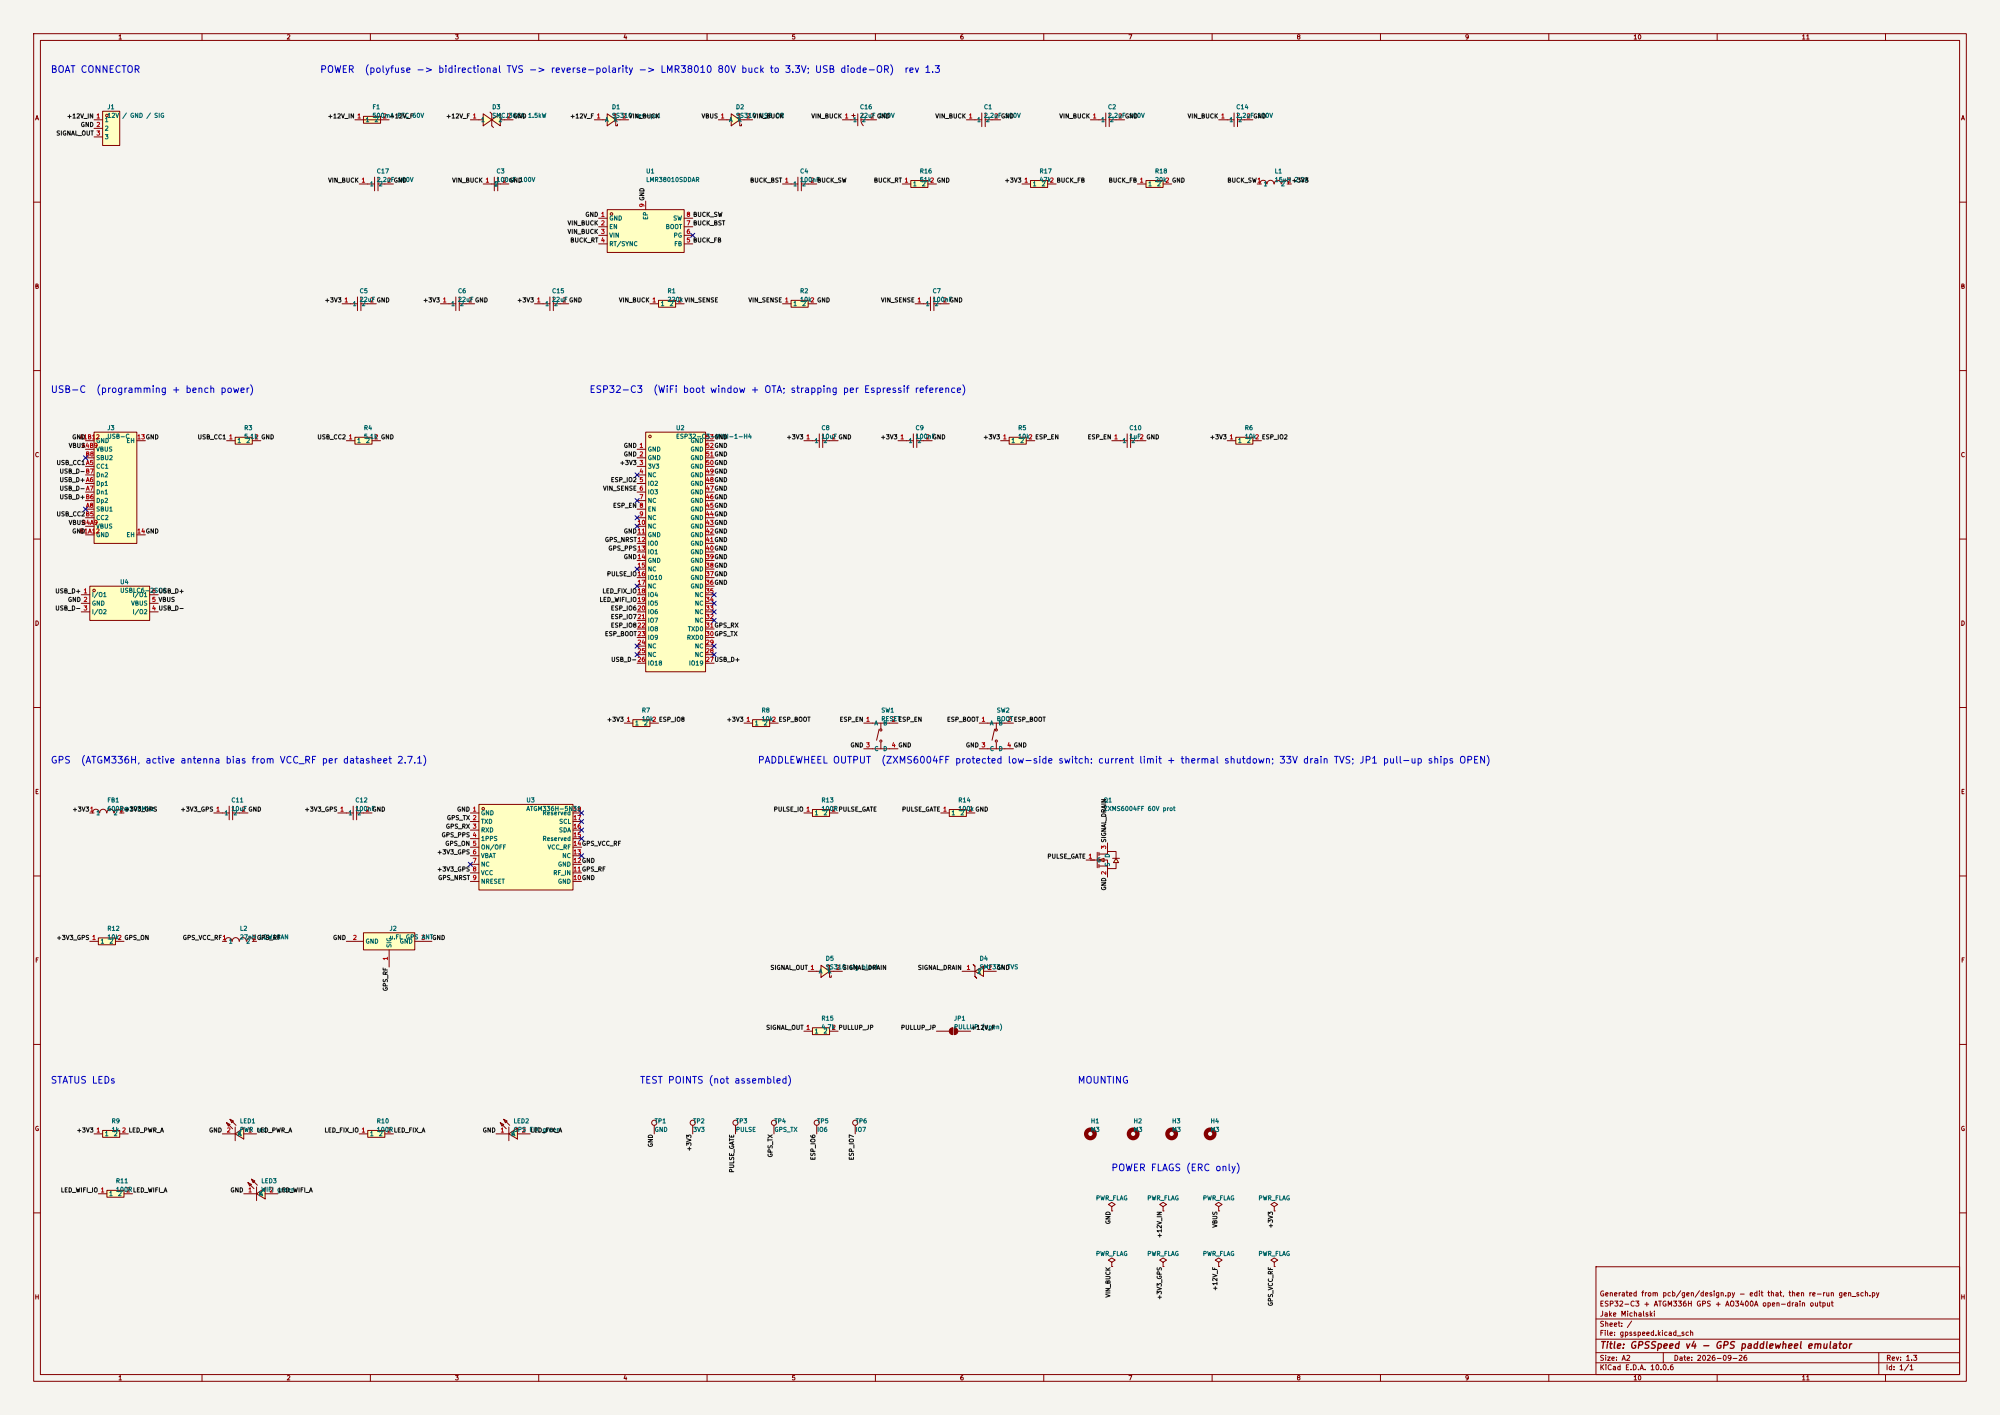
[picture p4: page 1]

USB-C (programming + bench power)

ESP32-C3 (WiFi boot window + OTA; strapping per Espressif reference)

GPS (ATGM336H, active antenna bias from VCC_RF per datasheet 2.7.1)

TEST POINTS (not assembled)

POWER FLAGS (ERC only)

Generated from pcb/gen/design.py - edit that, then re-run gen_sch.py
ESP32-C3 + ATGM336H GPS + AO3400A open-drain output
Jake Michalski
Sheet: /
File: gpsspeed.kicad_sch
Title: GPSSpeed v4 - GPS paddlewheel emulator

Size: A2 | Rev: 1.3
KiCad E.D.A. 10.0.6 | Id: 1/1

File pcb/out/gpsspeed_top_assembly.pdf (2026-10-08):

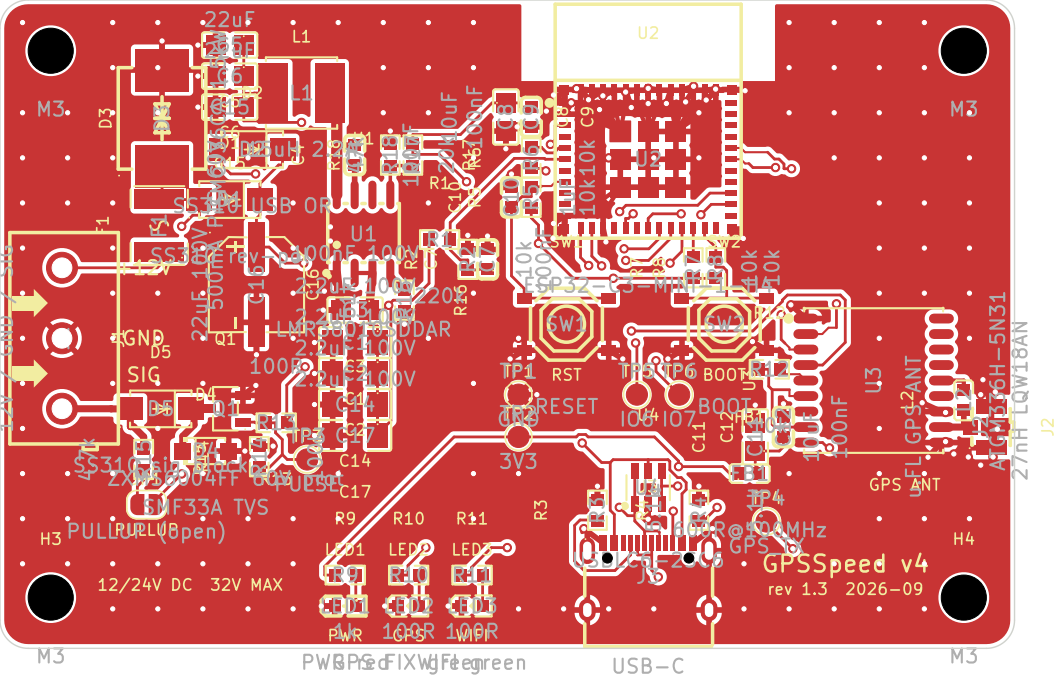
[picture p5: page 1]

rev 1.3 2026-09 GPS ANT +12V GND

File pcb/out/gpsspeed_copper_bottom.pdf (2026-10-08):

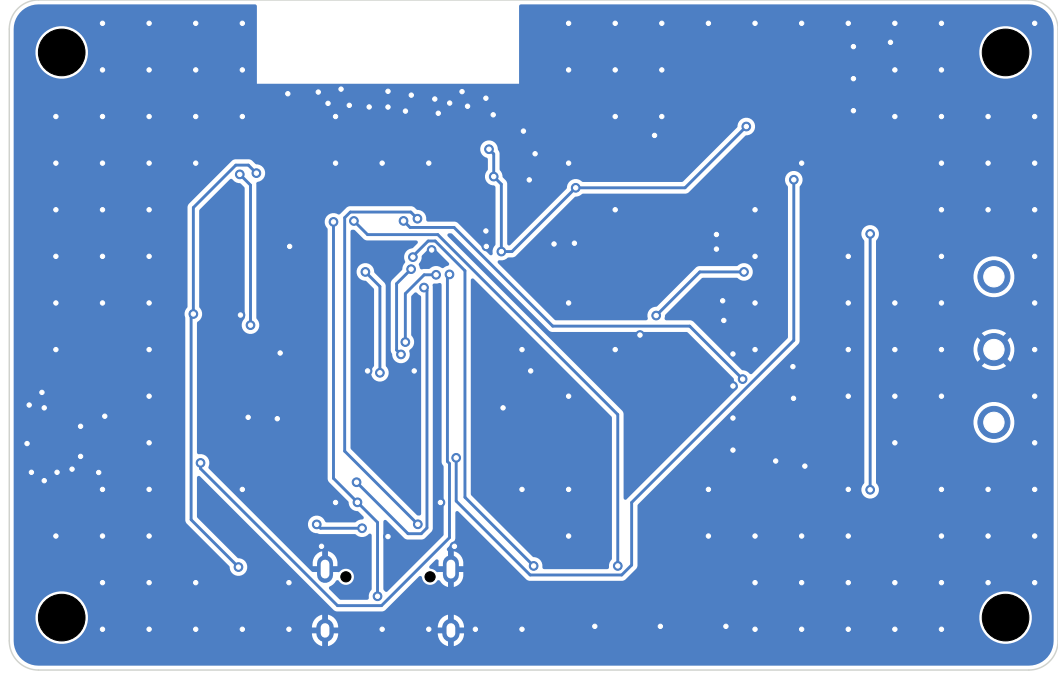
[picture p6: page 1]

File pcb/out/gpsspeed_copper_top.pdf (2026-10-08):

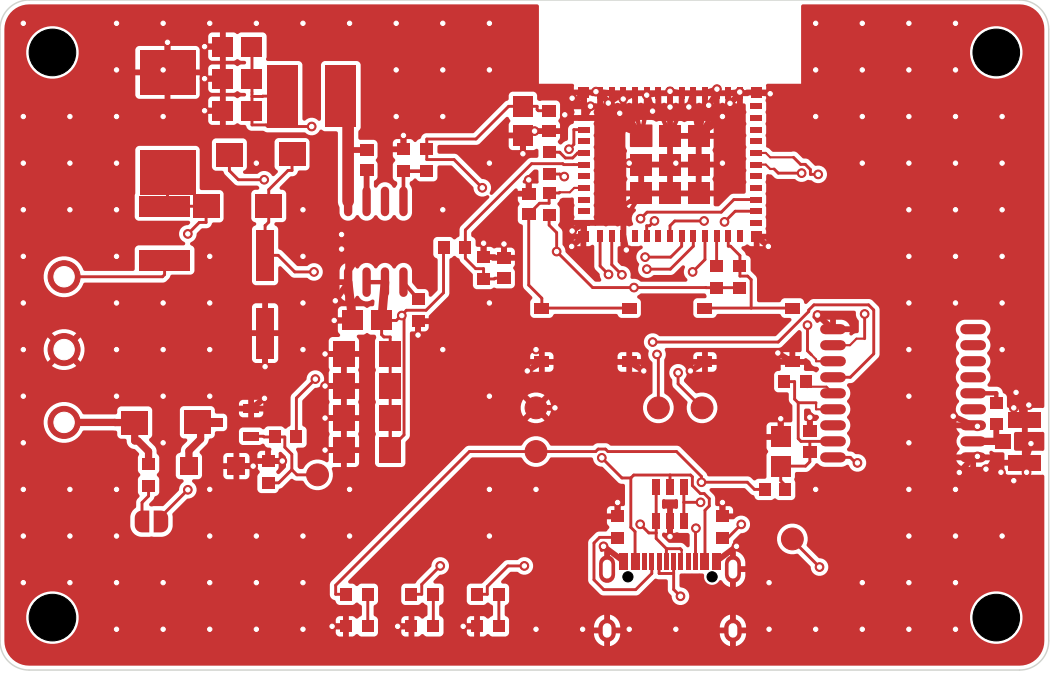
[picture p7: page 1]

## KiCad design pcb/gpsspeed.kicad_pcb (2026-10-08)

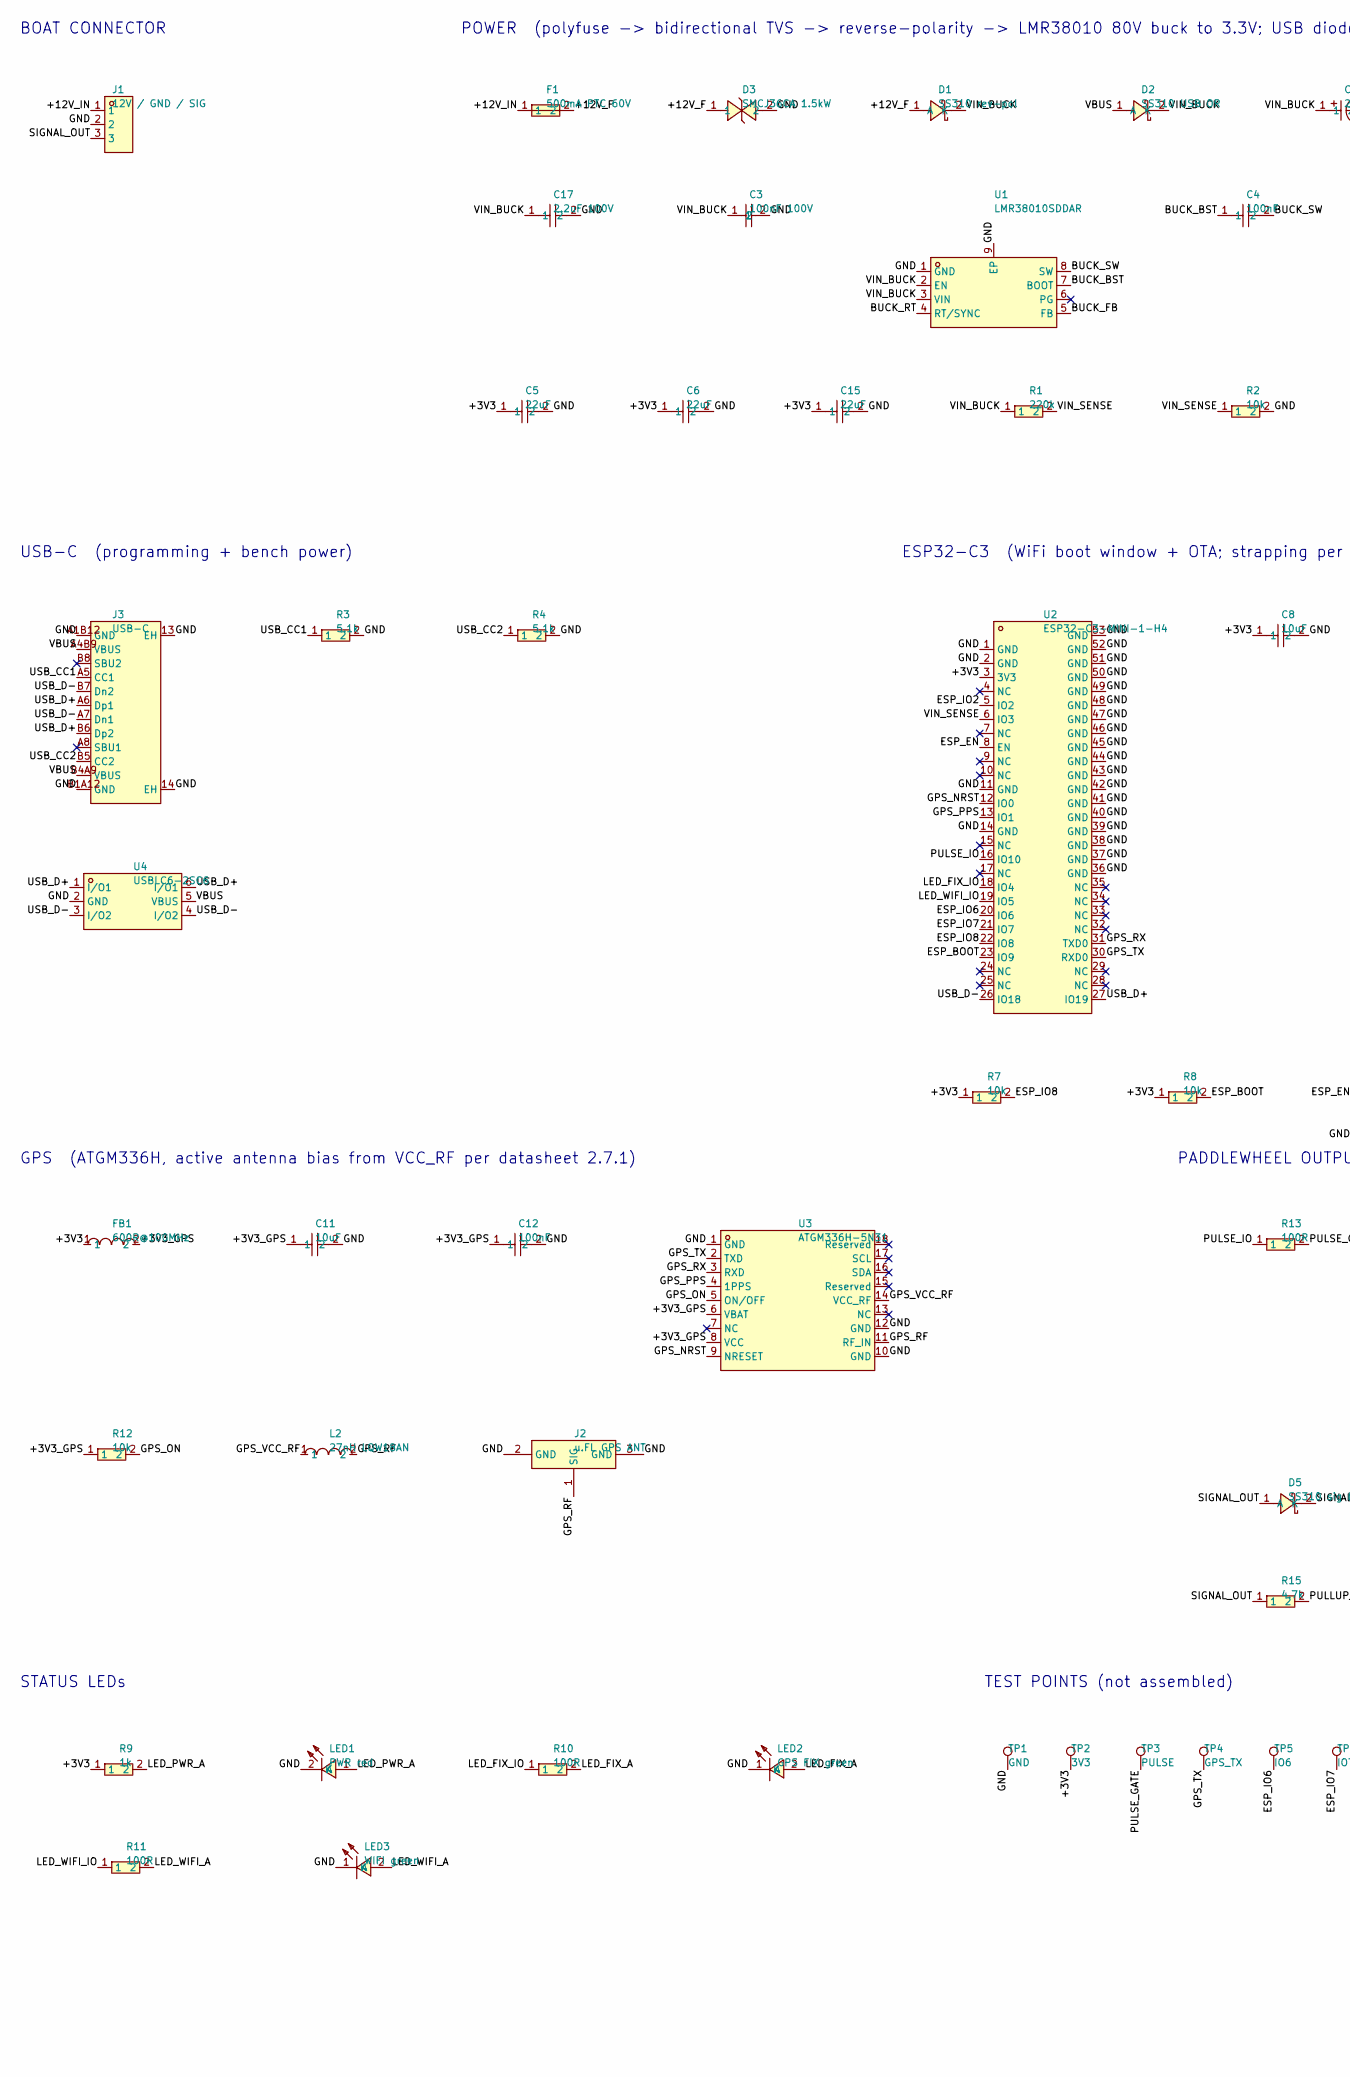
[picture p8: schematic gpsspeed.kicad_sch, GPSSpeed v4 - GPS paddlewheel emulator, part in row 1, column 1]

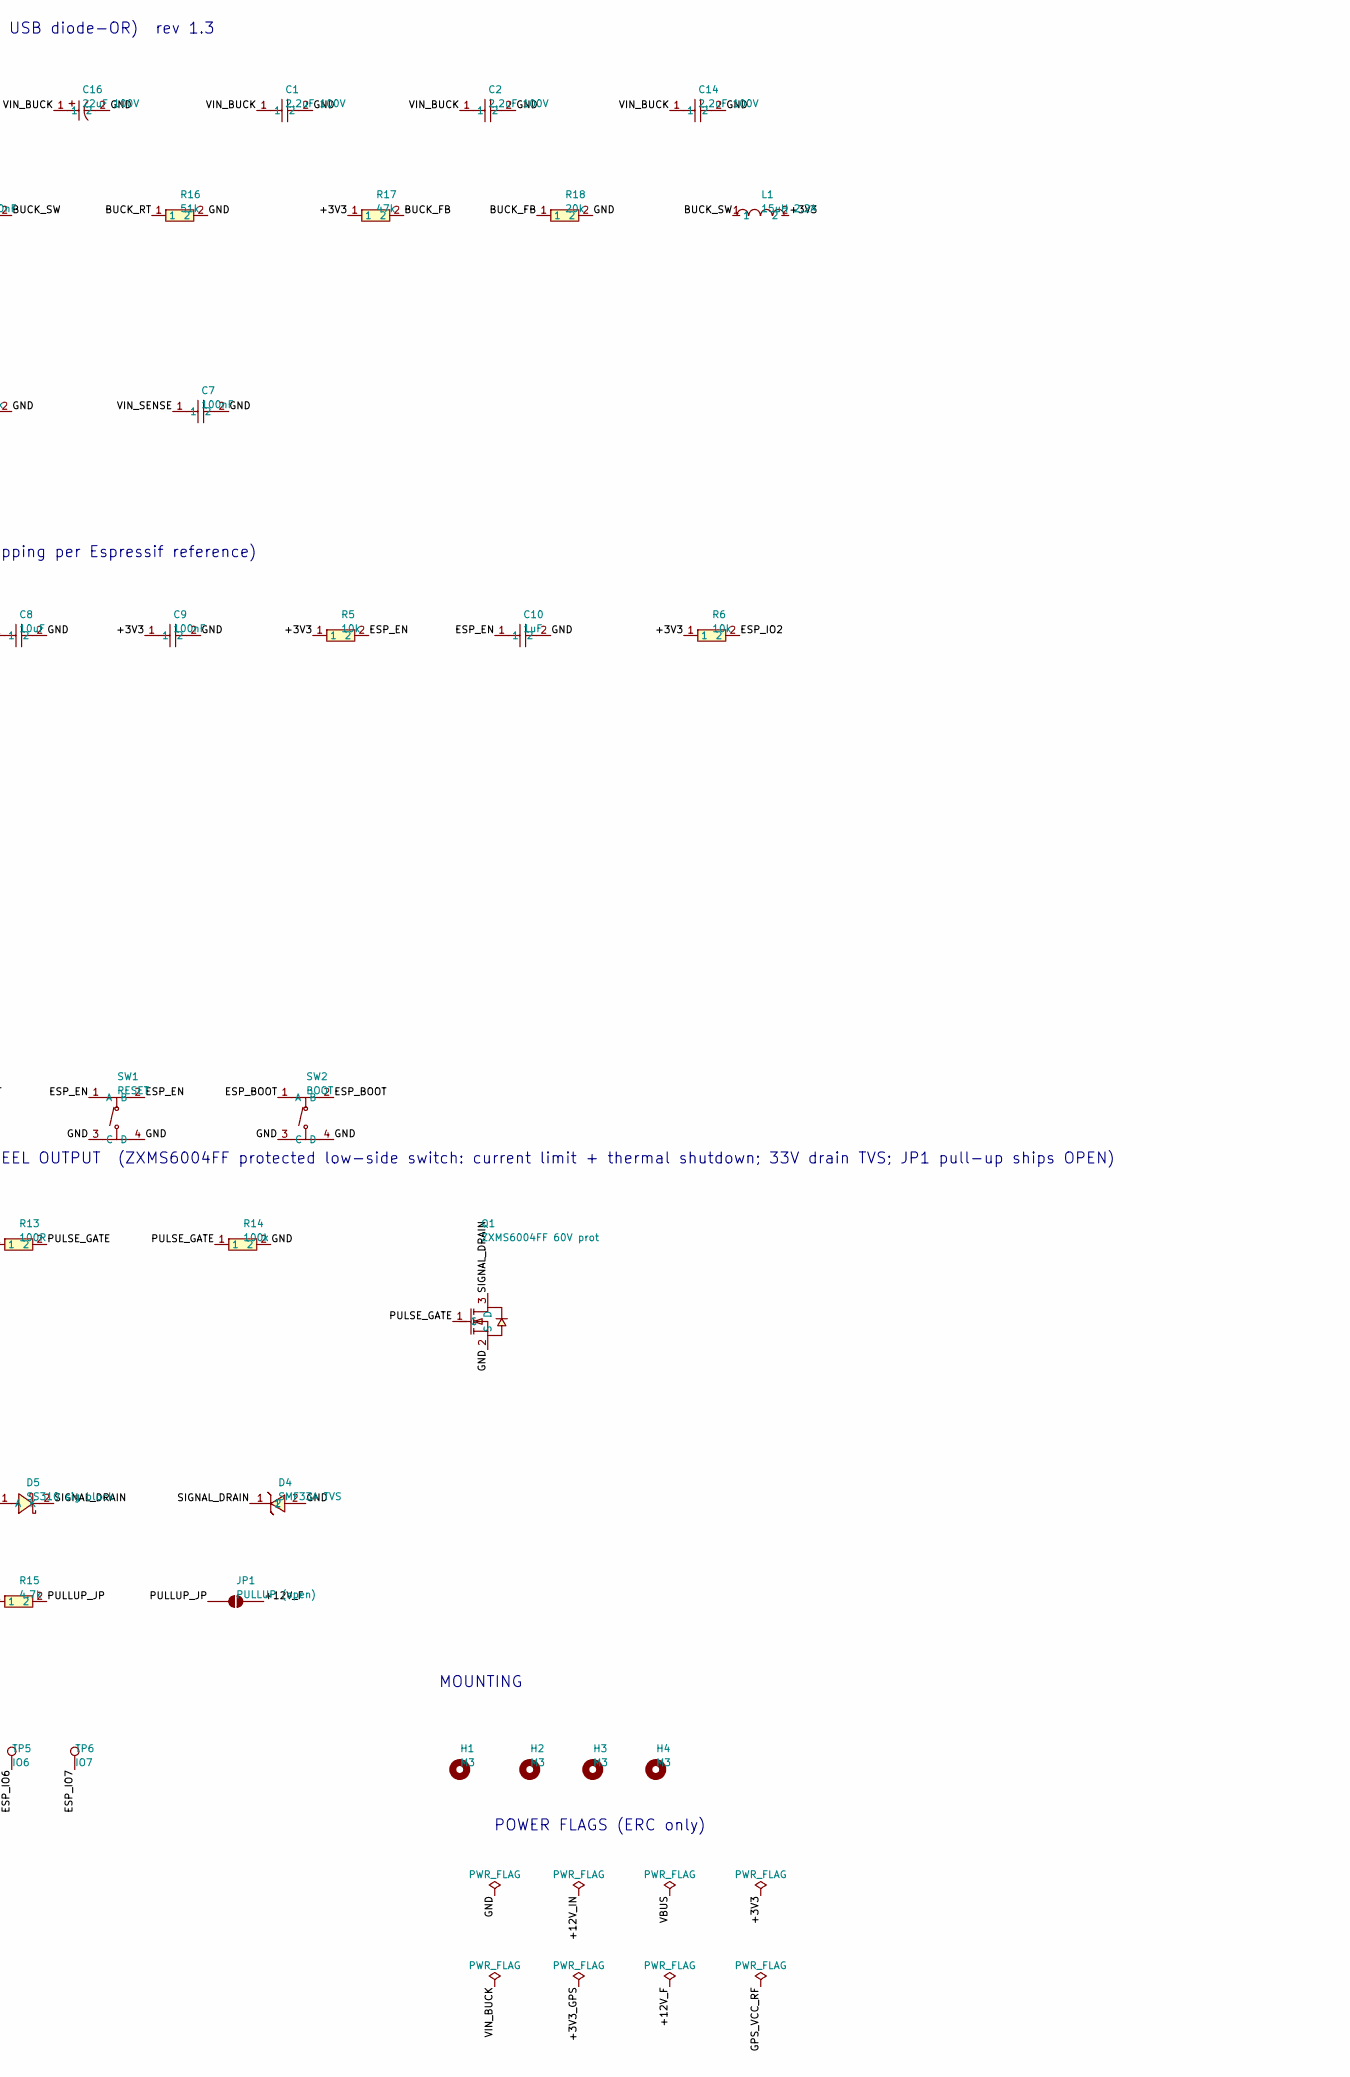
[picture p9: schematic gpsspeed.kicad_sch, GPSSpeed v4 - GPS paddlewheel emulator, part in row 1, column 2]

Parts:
C1, C2, C14, C17: 2.2uF 100V; C1206; LCSC C170101
C3: 100nF 100V; C0805; LCSC C28233
C4, C7, C9, C12: 100nF; C0603; LCSC C14663
C5, C6, C15: 22uF; C0805; LCSC C45783
C8, C11: 10uF; C0805; LCSC C15850
C10: 1uF; C0603; LCSC C15849
C16: 22uF 100V; CAP-SMD_BD6.3-L6.6-W6.6-LS7.4-FD; LCSC C48971012
D1: SS310 rev-pol; SMA_L4.3-W2.6-LS5.0-FD; LCSC C7420364
D2: SS310 USB OR; SMA_L4.3-W2.6-LS5.0-FD; LCSC C7420364
D3: SMCJ36CA 1.5kW; SMC_L6.9-W5.9-LS7.9-BI; LCSC C19077609
D4: SMF33A TVS; SOD-123FL_L2.7-W1.8-LS3.8-RD; LCSC C726914
D5: SS310 sig block; SMA_L4.3-W2.6-LS5.0-FD; LCSC C7420364
F1: 500mA PTC 60V; F1812; LCSC C19078719
FB1: 600R@100MHz; L0603; LCSC C1002
H1, H2, H3, H4: M3; MountingHole_3.2mm_M3
J1: 12V / GND / SIG; CONN-TH_3P-P5.00_KF301-5.0-3P; LCSC C474882
J2: u.FL GPS ANT; RF-SMD_FRF05002-JSS103M; LCSC C88374
J3: USB-C; USB-C-SMD_TYPE-C-16PIN-2MD-073; LCSC C2765186
JP1: PULLUP (open); SolderJumper-2_P1.3mm_Open_RoundedPad1.0x1.5mm
L1: 15uH 2.2A; IND-SMD_L5.0-W5.0; LCSC C167969
L2: 27nH LQW18AN; IND-SMD_L1.6-W0.8-1; LCSC C148128
LED1: PWR red; LED-SMD_L1.6-W0.8-R-RD; LCSC C2286
LED2: GPS FIX green; LED0603-RD; LCSC C12624
LED3: WIFI green; LED0603-RD; LCSC C12624
Q1: ZXMS6004FF 60V prot; SOT-23-3_L2.9-W1.6-P1.90-LS2.8-BR; LCSC C95063
R1: 220k; R0603; LCSC C22961
R2, R5, R6, R7, R8, R12: 10k; R0603; LCSC C25804
R3, R4: 5.1k; R0603; LCSC C23186
R9: 1k; R0603; LCSC C21190
R10, R11, R13: 100R; R0603; LCSC C22775
R14: 100k; R0603; LCSC C25803
R15: 4.7k; R0603; LCSC C23162
R16: 51k; R0603; LCSC C23196
R17: 47k; R0603; LCSC C25819
R18: 20k; R0603; LCSC C4184
SW1: RESET; SW-SMD_4P-L5.1-W5.1-P3.70-LS6.5-TL_H1.5; LCSC C318884
SW2: BOOT; SW-SMD_4P-L5.1-W5.1-P3.70-LS6.5-TL_H1.5; LCSC C318884
TP1: GND; TestPoint_Pad_D1.5mm
TP2: 3V3; TestPoint_Pad_D1.5mm
TP3: PULSE; TestPoint_Pad_D1.5mm
TP4: GPS_TX; TestPoint_Pad_D1.5mm
TP5: IO6; TestPoint_Pad_D1.5mm
TP6: IO7; TestPoint_Pad_D1.5mm
U1: LMR38010SDDAR; SOIC-8_L4.9-W3.9-P1.27-LS6.0-BL-EP-1; LCSC C5219310
U2: ESP32-C3-MINI-1-H4; WIFIM-SMD_ESP32-C3-MINI-1; LCSC C2934569
U3: ATGM336H-5N31; GPSM-SMD_ATGM336H-TR; LCSC C90770
U4: USBLC6-2SC6; SOT-23-6_L2.9-W1.6-P0.95-LS2.8-BL; LCSC C2687116

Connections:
+3V3: C5.1, C6.1, C8.1, C9.1, C15.1, FB1.1, L1.2, R5.1, R6.1, R7.1, R8.1, R9.1, R17.1, TP2.1, U2.3 (3V3)
+3V3_GPS: C11.1, C12.1, FB1.2, R12.1, U3.6 (VBAT), U3.8 (VCC)
+12V_F: D1.1 (A), D3.1, F1.2, JP1.2 (B)
+12V_IN: F1.1, J1.1
BUCK_BST: C4.1, U1.7 (BOOT)
BUCK_FB: R17.2, R18.1, U1.5 (FB)
BUCK_RT: R16.1, U1.4 (RT/SYNC)
BUCK_SW: C4.2, L1.1, U1.8 (SW)
ESP_BOOT: R8.2, SW2.1 (A), SW2.2 (B), U2.23 (IO9)
ESP_EN: C10.1, R5.2, SW1.1 (A), SW1.2 (B), U2.8 (EN)
ESP_IO2: R6.2, U2.5 (IO2)
ESP_IO6: TP5.1, U2.20 (IO6)
ESP_IO7: TP6.1, U2.21 (IO7)
ESP_IO8: R7.2, U2.22 (IO8)
GND: C1.2, C2.2, C3.2, C5.2, C6.2, C7.2, C8.2, C9.2, C10.2, C11.2, C12.2, C14.2, C15.2, C16.2, C17.2, D3.2, D4.2, J1.2, J2.2 (GND), J2.3 (GND), J3.13 (EH), J3.14 (EH), J3.A1B12 (GND), J3.B1A12 (GND), LED1.2 (K), LED2.1 (K), LED3.1 (K), Q1.2 (S), R2.2, R3.2, R4.2, R14.2, R16.2, R18.2, SW1.3 (C), SW1.4 (D), SW2.3 (C), SW2.4 (D), TP1.1, U1.1 (GND), U1.9 (EP), U2.1 (GND), U2.2 (GND), U2.11 (GND), U2.14 (GND), U2.36 (GND), U2.37 (GND), U2.38 (GND), U2.39 (GND), U2.40 (GND), U2.41 (GND), U2.42 (GND), U2.43 (GND), U2.44 (GND), U2.45 (GND), U2.46 (GND), U2.47 (GND), U2.48 (GND), U2.49 (GND), U2.50 (GND), U2.51 (GND), U2.52 (GND), U2.53 (GND), U3.1 (GND), U3.10 (GND), U3.12 (GND), U4.2 (GND)
GPS_NRST: U2.12 (IO0), U3.9 (NRESET)
GPS_ON: R12.2, U3.5 (ON/OFF)
GPS_PPS: U2.13 (IO1), U3.4 (1PPS)
GPS_RF: J2.1 (SIG), L2.2, U3.11 (RF_IN)
GPS_RX: U2.31 (TXD0), U3.3 (RXD)
GPS_TX: TP4.1, U2.30 (RXD0), U3.2 (TXD)
GPS_VCC_RF: L2.1, U3.14 (VCC_RF)
LED_FIX_A: LED2.2 (A), R10.2
LED_FIX_IO: R10.1, U2.18 (IO4)
LED_PWR_A: LED1.1 (A), R9.2
LED_WIFI_A: LED3.2 (A), R11.2
LED_WIFI_IO: R11.1, U2.19 (IO5)
PULLUP_JP: JP1.1 (A), R15.2
PULSE_GATE: Q1.1 (G), R13.2, R14.1, TP3.1
PULSE_IO: R13.1, U2.16 (IO10)
SIGNAL_DRAIN: D4.1, D5.2 (K), Q1.3 (D)
SIGNAL_OUT: D5.1 (A), J1.3, R15.1
USB_CC1: J3.A5 (CC1), R3.1
USB_CC2: J3.B5 (CC2), R4.1
USB_D+: J3.A6 (Dp1), J3.B6 (Dp2), U2.27 (IO19), U4.1 (I/O1), U4.6 (I/O1)
USB_D-: J3.A7 (Dn1), J3.B7 (Dn2), U2.26 (IO18), U4.3 (I/O2), U4.4 (I/O2)
VBUS: D2.1 (A), J3.A4B9 (VBUS), J3.B4A9 (VBUS), U4.5 (VBUS)
VIN_BUCK: C1.1, C2.1, C3.1, C14.1, C16.1, C17.1, D1.2 (K), D2.2 (K), R1.1, U1.2 (EN), U1.3 (VIN)
VIN_SENSE: C7.1, R1.2, R2.1, U2.6 (IO3)

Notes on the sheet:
BOAT CONNECTOR
POWER (polyfuse -> bidirectional TVS -> reverse-polarity -> LMR38010 80V buck to 3.3V; USB diode-OR) rev 1.3
USB-C (programming + bench power)
ESP32-C3 (WiFi boot window + OTA; strapping per Espressif reference)
GPS (ATGM336H, active antenna bias from VCC_RF per datasheet 2.7.1)
PADDLEWHEEL OUTPUT (ZXMS6004FF protected low-side switch: current limit + thermal shutdown; 33V drain TVS; JP1 pull-up ships OPEN)
STATUS LEDs
TEST POINTS (not assembled)
MOUNTING
POWER FLAGS (ERC only)

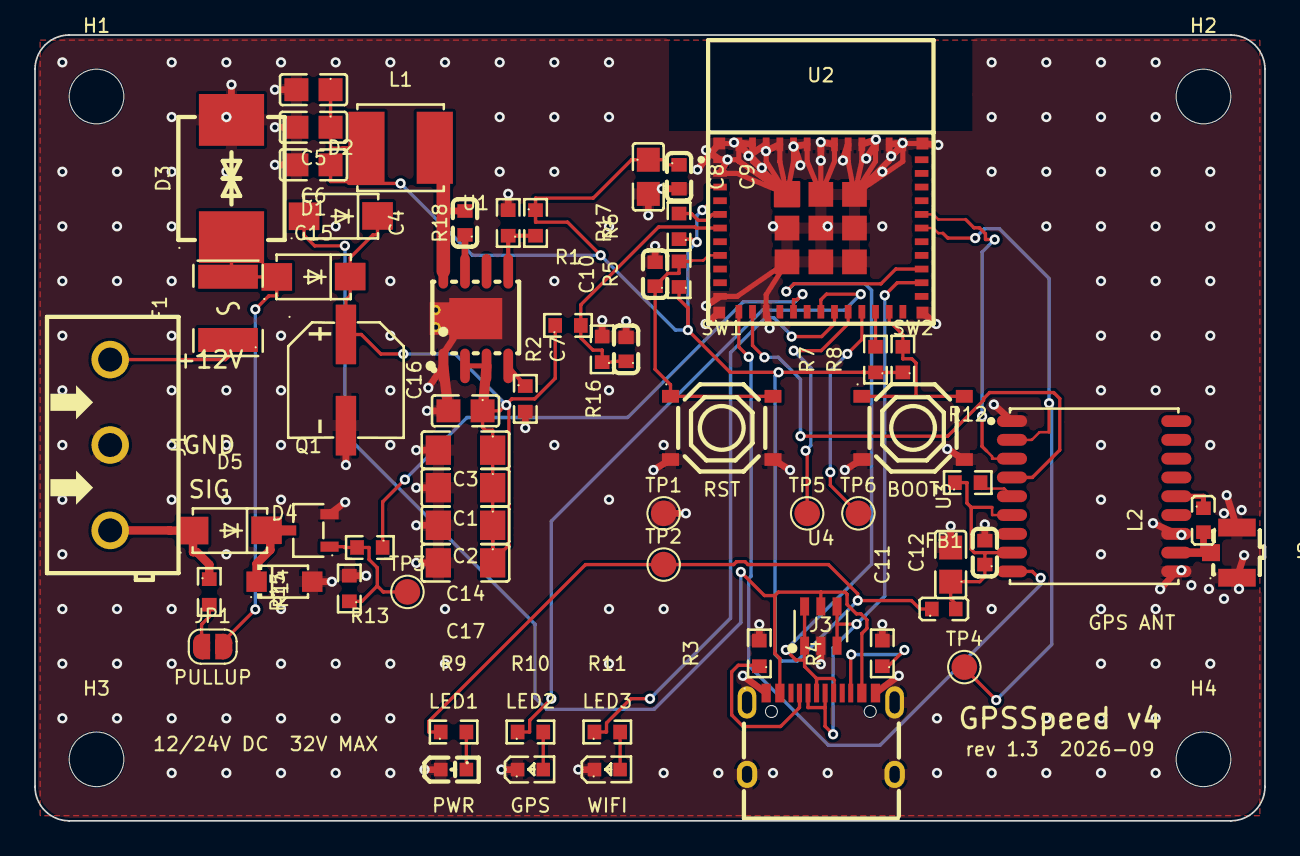
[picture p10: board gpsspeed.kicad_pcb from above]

Board: 2 copper layers, 72.0 x 46.0 mm, 67 parts (0 on the bottom side), 39 nets.

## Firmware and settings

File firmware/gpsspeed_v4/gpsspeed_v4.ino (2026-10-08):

/**
 * @file gpsspeed_v4.ino
 * @author Jake Michalski
 * @brief GPS -> paddlewheel pulse emulator for PerfectPass, on the ESP32-C3 board.
 * @version 4.0.0
 * @date 2026-09-26
 *
 * @copyright Copyright MIT License (c) 2025-2026
 *
 * HARDWARE: pcb/ in this repo (ESP32-C3-MINI-1 + ATGM336H + ZXMS6004FF output), board rev 1.2+.
 * Not for the Uno perfboard -- that's v2/ and v3/.
 *
 * WHAT CHANGED FROM THE UNO BUILDS
 * --------------------------------
 *  - The paddlewheel square wave comes from the LEDC hardware peripheral off
 *    the 40 MHz crystal. Nothing in software can stretch it, so the old
 *    ~21 MPH cliff (SoftwareSerial blocking the pulse loop) cannot happen.
 *  - GPS is on a real hardware UART at 115200 baud, 10 Hz.
 *  - No more one-serial-port juggling: the USB-C serial monitor is always
 *    available alongside the GPS.
 *  - Everything tunable lives in flash and is edited from a phone:
 *      power on -> join WiFi "GPSSpeed-XXXX" (open) -> gpsspeed.local
 *    The access point shuts itself off after the boot window (default 2 min,
 *    extended while a phone is connected), so the radio is quiet underway.
 *  - Firmware updates over WiFi, with automatic rollback if a new build
 *    crash-loops -- safe to pot the board in resin.
 *
 * LEDs
 * ----
 *   PWR  red    board has 3.3 V
 *   GPS  green  solid = fix | 2 blinks = GPS talking, no fix | 1 blink = no GPS data
 *               fast flicker = manual / self-test output (NOT following the GPS)
 *   WIFI green  solid = access point up | blinking = phone connected | off = radio off
 *
 * BUILD
 * -----
 *   arduino-cli compile --fqbn esp32:esp32:esp32c3:CDCOnBoot=cdc,PartitionScheme=min_spiffs firmware/gpsspeed_v4
 *   (min_spiffs = two 1.9 MB OTA slots. Keep it: OTA can never change the partition table.)
 *   Needs TinyGPSPlus. First flash over USB-C; after that, OTA from the web UI.
 */

#include "config.h"
#include "safety.h"
#include "settings.h"
#include "pulse.h"
#include "gps.h"
#include "app.h"
#include "web.h"

static void ledFixTick() {
  uint32_t now = millis();
  bool on;
  if (mode != MODE_NORMAL) {
    on = (now / 125) & 1;                     // fast flicker: not on GPS
  } else if (gpsHaveFix()) {
    on = true;
  } else {
    uint8_t blinks = gpsTalking() ? 2 : 1;
    uint32_t ph = now % 1600;
    on = false;
    for (uint8_t i = 0; i < blinks; i++)
      if (ph >= i * 250UL && ph < i * 250UL + 100UL) on = true;
  }
  digitalWrite(PIN_LED_FIX, on);
}

// USB serial console. Type `help`.
static void serialTick() {
  static String line;
  while (Serial.available()) {
    char c = Serial.read();
    if (c != '\n' && c != '\r') { if (line.length() < 64) line += c; continue; }
    line.trim();
    if (!line.length()) continue;
    int sp = line.indexOf(' ');
    String cmd = sp < 0 ? line : line.substring(0, sp);
    float arg = sp < 0 ? NAN : line.substring(sp + 1).toFloat();
    cmd.toLowerCase();
    if (cmd == "speed" && !isnan(arg)) { setModeManual(arg); Serial.printf("manual %.2f MPH\n", manualMph); }
    else if (cmd == "run" || cmd == "gps") { setModeNormal(); Serial.println("normal (GPS)"); }
    else if (cmd == "selftest") { selftestStart(); Serial.println("self-test"); }
    else if (cmd == "next") { selftestNext(); }
    else if (cmd == "dash" && !isnan(arg)) {
      bool ok = mode != MODE_NORMAL && calAddPoint(outMph, arg);
      if (ok) { settingsSave(); pulseSetMph(outMph); }
      Serial.println(ok ? "calibration point saved" : "rejected (hold a speed first)");
    }
    else if (cmd == "k" && !isnan(arg) && arg > 1 && arg < 20) { cfg.hzPerMph = arg; settingsSave(); pulseSetMph(outMph); Serial.printf("Hz/MPH = %.4f\n", cfg.hzPerMph); }
    else if (cmd == "nofix" && !isnan(arg)) { cfg.noFixMph = constrain(arg, 0.0f, 30.0f); settingsSave(); Serial.printf("no-fix = %.2f MPH\n", cfg.noFixMph); }
    else if (cmd == "calclear") { cfg.calCount = 0; settingsSave(); pulseSetMph(outMph); Serial.println("calibration cleared"); }
    else if (cmd == "wifi") { if (!wifiOn) wifiStart(); wifiKeep = true; Serial.println("WiFi on until reboot"); }
    else if (cmd == "reboot") { ESP.restart(); }
    else {
      Serial.println("commands: speed <mph> | run | selftest | next | dash <mph> | k <hz/mph> |");
      Serial.println("          nofix <mph> | calclear | wifi | reboot");
    }
    line = "";
  }
}

// One line a second, label:value pairs (works in the Serial Plotter too).
static void heartbeat() {
  static uint32_t last = 0;
  static int lastStep = -2;
  if (mode == MODE_SELFTEST && stIdx != lastStep) {
    lastStep = stIdx;
    Serial.printf("[self-test] step %d -> %.1f MPH = %.2f Hz  (read the dash; `dash <mph>` to calibrate)\n",
                  stIdx + 1, outMph, pulseHz);
  }
  if (millis() - last < 1000) return;
  last = millis();
  Serial.printf("sats:%u chars:%lu fix:%d age:%ld raw:%.2f out:%.2f hz:%.3f vin:%.1f mode:%s ant:%s\n",
                (unsigned)gps.satellites.value(), (unsigned long)gps.charsProcessed(), gpsHaveFix(),
                gpsEverFix ? (long)(millis() - gpsLastFixMs) : 9999L, rawMph, outMph, pulseHz,
                batteryVolts(), modeName(), gpsAntenna);
}

void setup() {
  safetyBoot();                       // may roll back a crash-looping update
  Serial.begin(115200);

  pinMode(PIN_LED_FIX, OUTPUT);
  pinMode(PIN_LED_WIFI, OUTPUT);
  analogSetPinAttenuation(PIN_VSENSE, ADC_11db);

  settingsLoad();

  // Dash first: steady no-fix speed from the very first moment.
  pulseInit();
  outMph = cfg.noFixMph;
  pulseSetMph(outMph);

  wifiStart();
  gpsBegin();

  Serial.printf("\nGPSSpeed v%s  reset:%s  Hz/MPH:%.4f  no-fix:%.1f  GPS:%lu baud @ %u Hz\n",
                FW_VERSION, resetReasonStr(), cfg.hzPerMph, cfg.noFixMph,
                (unsigned long)gpsBaud, gpsRate);
}

void loop() {
  bool fresh = gpsPoll();
  updateOutput(fresh);
  wifiTick();
  ledFixTick();
  serialTick();
  heartbeat();
  safetyTick();
}

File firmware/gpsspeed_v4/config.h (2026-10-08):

// GPSSpeed v4 -- pin map and defaults for the ESP32-C3 board (pcb/).
//
// The pin map must match pcb/gen/design.py (the GPIO dict). If you change
// one, change the other.
#pragma once

#define FW_VERSION "4.0.8"   // 4.0.8: tidier open/tips card; 4.0.7: Open-in-browser; 4.0.6: open WiFi; 4.0.5: pop-up app + Done; 4.0.4: stable SSID; 4.0.3: gpsspeed.local

// ---------------------------------------------------------------- pins ----
#define PIN_GPS_RX      20   // ESP RX  <- GPS TXD
#define PIN_GPS_TX      21   // ESP TX  -> GPS RXD
#define PIN_GPS_NRST     0   // GPS reset, active low (left as input = released)
#define PIN_GPS_PPS      1   // GPS 1PPS, rising edge on the UTC second
#define PIN_VSENSE       3   // boat battery through 220k/10k divider (x23), after D1
#define PIN_LED_FIX      4   // green, "GPS"
#define PIN_LED_WIFI     5   // green, "WIFI"
#define PIN_PULSE       10   // -> 100R -> Q1 (ZXMS6004FF) input. HIGH = line pulled low.
#define PIN_BOOT         9   // BOOT button (also the strapping pin)

#define VSENSE_RATIO  23.0f  // (220k + 10k) / 10k  (board rev 1.2; rev 1.1 was 16)
// The divider is tapped after the SS310 reverse-polarity diode, so on boat
// power it reads one diode drop low. Added back when running above USB levels.
#define VSENSE_DIODE_V 0.35f

// -------------------------------------------------------------- defaults --
// All of these are editable from the web UI and persist in NVS.

// Output frequency per commanded MPH.
//
// The Uno builds used 4.38, but that number was tuned against a pulse
// generator that FLOORED every half-period to a multiple of 128 us. That
// rounding made the Uno's real output run ~1-2% fast, so its *effective*
// constant across 15-26 MPH was ~4.42 Hz/MPH. v4 generates the frequency
// exactly (hardware LEDC off the 40 MHz crystal), so to make the dash read
// what it read before, the default starts at the Uno's effective value.
// Run the self-test once on the boat and fine-tune from the web UI.
#define DEF_HZ_PER_MPH     4.42f

#define DEF_NO_FIX_MPH     5.0f    // steady value until GPS lock (never swept)
#define DEF_MIN_MPH        0.6f    // below this we stop pulsing (dash shows 0)
#define DEF_LEAD_SEC       0.30f   // predictor look-ahead
#define DEF_ACCEL_ALPHA    0.40f   // predictor smoothing (0..1)
#define DEF_GPS_RATE_HZ    10
#define DEF_BOOT_WINDOW_S  120     // WiFi AP stays up this long after power-on
#define DEF_AP_PASS        ""          // open network; set one from the page if wanted

#define FIX_TIMEOUT_MS     3000    // no fresh fix this long => NO_FIX_MPH
#define CLIENT_GRACE_MS    60000   // keep WiFi up this long after last client leaves
#define MAX_MPH            60.0f
#define CAL_POINTS         8

// Self-test sequence (MPH). Each step holds for SELFTEST_STEP_MS unless you
// advance it from the web UI / serial.
static const float SELFTEST_SPEEDS[] = {0, 10, 15, 20, 22, 24, 26, 30};
#define SELFTEST_STEP_MS   15000

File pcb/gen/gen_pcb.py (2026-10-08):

"""Generate gpsspeed.kicad_pcb (placement, outline, keepouts, pours, RF
pre-routes) from design.PARTS. Autorouting and outputs happen in build.py.

Run with KiCad's bundled Python (it provides the pcbnew module).

Board: 72 x 46 mm, 2 layers, 1.6 mm FR4.
  Left edge  : J1 screw terminal, wires exit off the left edge
  Top-left   : 12V input protection + LMR38010 buck
  Top-middle : ESP32-C3, PCB antenna flush with the top edge over a keepout
  Right      : ATGM336H GPS, u.FL at the right edge (~2 mm RF trace)
  Bottom     : USB-C at the bottom edge, status LEDs, output stage near J1
"""
import os
import sys
import uuid

import pcbnew

HERE = os.path.dirname(os.path.abspath(__file__))
sys.path.insert(0, HERE)
import design  # noqa: E402
from symlib import PROJ, PROJECT_FOOTPRINTS, STOCK_FOOTPRINTS, Symbol  # noqa: E402
from gen_sch import ROOT, uid  # noqa: E402

W, H = 72.0, 46.0
MM = pcbnew.FromMM

# ref -> (x, y, rotation_deg).  Rotation follows KiCad: +90 is CCW on screen.
PLACE = {
    # boat connector: rot 270 puts pin 1 (+12V) on top and the wire entry
    # (the silkscreen arrows) facing off the left edge
    "J1": (4.4, 24.0, 270),

    # --- 12V input chain (rev 1.1): fuse -> TVS -> diode, stacked by J1 ---
    "F1": (11.3, 16.0, 90),        # 1812 PTC, pad 1 (+12V_IN) at the bottom by J1.1
    "D3": (11.5, 8.4, 90),         # SMCJ36CA, pad 1 (+12V_F) at the bottom
    "D1": (16.3, 14.15, 0),        # SS310: anode left (from fuse), cathode right
    "D2": (17.9, 10.6, 0),         # SS310 USB OR: VBUS left, VIN_BUCK right
    "C16": (18.2, 20.2, 270),      # 22uF/100V bulk, pad 1 (+) on top
    # --- LMR38010 buck: VIN/GND pins face down onto the input caps ---
    "U1": (25.8, 16.6, 0),
    "C3": (25.2, 22.0, 180),       # 100nF 100V directly under VIN(3)/GND(1): ~2mm loop
    "C1": (25.2, 24.3, 180),
    "C2": (25.2, 26.5, 180),
    "C14": (25.2, 28.7, 180),
    "C17": (25.2, 30.9, 180),      # rev 1.2: 4th input ceramic
    "R16": (28.7, 21.3, 270),      # RT, right at pin 4
    "C4": (25.17, 11.0, 90),       # BOOT cap, straight above pin 7
    "L1": (21.4, 6.6, 0),          # SW pad directly above pin 8
    "C5": (16.3, 3.2, 180),
    "C6": (16.3, 5.4, 180),
    "C15": (16.3, 7.6, 180),
    "R18": (27.7, 11.0, 90),       # FB divider on the quiet side, away from SW/L1
    "R17": (29.3, 11.0, 270),
    # battery-voltage divider, tapped after D1
    "R1": (31.2, 17.0, 0),
    "R2": (33.2, 18.4, 90),
    "C7": (34.6, 18.4, 90),

    # --- ESP32-C3, antenna flush with the top edge ---
    "U2": (46.0, 11.3, 0),
    "C8": (35.9, 8.3, 270),
    "C9": (37.7, 8.3, 270),
    "R6": (37.7, 11.2, 90),        # IO2 strap
    "R5": (37.7, 14.0, 90),        # EN pull-up
    "C10": (36.3, 14.0, 90),       # EN delay cap
    "R7": (49.2, 19.0, 90),        # IO8 strap
    "R8": (50.8, 19.0, 90),        # IO9 / BOOT pull-up
    "SW1": (40.2, 23.0, 0),        # RESET
    "SW2": (51.4, 23.0, 0),        # BOOT (clear of the GPS pads)

    # --- USB-C at the bottom edge ---
    "J3": (46.0, 40.9, 0),
    "U4": (46.0, 34.6, 0),
    "R3": (42.4, 36.2, 90),
    "R4": (49.6, 36.2, 90),

    # --- GPS on the right, RF pins facing the right edge ---
    "U3": (62.0, 27.0, 90),
    "J2": (69.6, 30.3, 270),       # u.FL, signal pad faces the GPS
    "L2": (68.4, 28.4, 90),        # LQW18AN bias choke, pad 1 (VCC_RF) on top
    "FB1": (53.2, 33.6, 0),
    "C11": (53.6, 31.0, 90),
    "C12": (55.6, 30.3, 90),       # right at GPS VCC
    "R12": (54.6, 26.2, 0),        # ON/OFF pull-up

    # --- paddlewheel output stage, next to J1 pin 3 ---
    "D5": (11.4, 29.0, 0),         # series Schottky: anode at the terminal
    "Q1": (16.0, 29.0, 0),         # drain faces D5, gate/source face right
    "D4": (14.6, 32.0, 0),         # drain clamp: cathode toward the drain node
    "R13": (19.6, 30.0, 180),      # gate end toward Q1
    "R14": (18.4, 32.4, 90),
    "R15": (10.2, 32.6, 270),      # optional pull-up, on the terminal side of D5
    "JP1": (10.4, 35.8, 0),

    # --- status LEDs along the bottom (visible through clear potting) ---
    "R9": (24.5, 40.8, 0),  "LED1": (24.5, 43.0, 0),
    "R10": (29.0, 40.8, 0), "LED2": (29.0, 43.0, 0),
    "R11": (33.5, 40.8, 0), "LED3": (33.5, 43.0, 0),

    # --- test points ---
    "TP1": (36.8, 28.0, 0),  "TP2": (36.8, 31.0, 0),
    "TP3": (21.8, 32.6, 0),  "TP4": (54.4, 37.0, 0),
    "TP5": (45.2, 28.0, 0),  "TP6": (48.2, 28.0, 0),

    # --- mounting ---
    "H1": (3.6, 3.6, 0), "H2": (68.4, 3.6, 0),
    "H3": (3.6, 42.4, 0), "H4": (68.4, 42.4, 0),
}

SILK = [
    # (text, x, y, size, layer)
    ("+12V", 10.2, 19.0, 1.0, "F"), ("GND", 10.2, 24.0, 1.0, "F"), ("SIG", 10.2, 26.6, 1.0, "F"),
    ("PWR", 24.5, 45.1, 0.8, "F"), ("GPS", 29.0, 45.1, 0.8, "F"), ("WIFI", 33.5, 45.1, 0.8, "F"),
    ("RST", 40.2, 26.6, 0.8, "F"), ("BOOT", 51.4, 26.6, 0.8, "F"),
    ("GPS ANT", 64.2, 34.4, 0.8, "F"), ("PULLUP", 10.4, 37.6, 0.8, "F"),
    ("GPSSpeed v4", 60.0, 40.0, 1.2, "F"), ("rev 1.3  2026-09", 60.0, 41.8, 0.8, "F"),
    ("12/24V DC  32V MAX", 13.5, 41.5, 0.8, "F"),
    ("GPSSpeed v4 - ESP32-C3 + ATGM336H", 36.0, 30.0, 1.0, "B"),
    ("JP1 ships OPEN: bridge only if dash has no pull-up (12V boats)", 36.0, 32.0, 0.8, "B"),
    ("JLCJLCJLCJLC", 36.0, 34.5, 0.8, "B"),
]


def fp_source(part):
    fp = part.get("fp") or Symbol(part["sym"]).footprint
    lib, name = fp.split(":", 1)
    path = PROJECT_FOOTPRINTS if lib == "gpsspeed" else os.path.join(STOCK_FOOTPRINTS, lib + ".pretty")
    return path, name, fp


def add_outline(board):
    r = 2.0
    def seg(a, b):
        s = pcbnew.PCB_SHAPE(board, pcbnew.SHAPE_T_SEGMENT)
        s.SetStart(pcbnew.VECTOR2I(MM(a[0]), MM(a[1]))); s.SetEnd(pcbnew.VECTOR2I(MM(b[0]), MM(b[1])))
        s.SetLayer(pcbnew.Edge_Cuts); s.SetWidth(MM(0.1)); board.Add(s)
    def arc(c, start, end):
        s = pcbnew.PCB_SHAPE(board, pcbnew.SHAPE_T_ARC)
        s.SetCenter(pcbnew.VECTOR2I(MM(c[0]), MM(c[1])))
        s.SetStart(pcbnew.VECTOR2I(MM(start[0]), MM(start[1])))
        s.SetEnd(pcbnew.VECTOR2I(MM(end[0]), MM(end[1])))
        s.SetLayer(pcbnew.Edge_Cuts); s.SetWidth(MM(0.1)); board.Add(s)
    seg((r, 0), (W - r, 0)); seg((W, r), (W, H - r)); seg((W - r, H), (r, H)); seg((0, H - r), (0, r))
    arc((W - r, r), (W - r, 0), (W, r))
    arc((W - r, H - r), (W, H - r), (W - r, H))
    arc((r, H - r), (r, H), (0, H - r))
    arc((r, r), (0, r), (r, 0))


def poly(pts):
    chain = pcbnew.SHAPE_LINE_CHAIN()
    for x, y in pts:
        chain.Append(MM(x), MM(y))
    chain.SetClosed(True)
    return chain


def add_zone(board, net, layer, pts, priority=0):
    z = pcbnew.ZONE(board)
    z.SetLayer(layer)
    z.SetNet(net)
    z.Outline().AddOutline(poly(pts))
    z.SetLocalClearance(MM(0.3))
    z.SetMinThickness(MM(0.25))
    z.SetPadConnection(pcbnew.ZONE_CONNECTION_THERMAL)
    z.SetThermalReliefGap(MM(0.3))
    z.SetThermalReliefSpokeWidth(MM(0.4))
    z.SetAssignedPriority(priority)
    board.Add(z)
    return z
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

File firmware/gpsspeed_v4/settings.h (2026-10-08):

// Persistent settings (NVS via Preferences). Everything the web UI can edit.
#pragma once
#include <Preferences.h>
#include "config.h"

struct CalPoint {
  float mph;      // commanded speed where this point was measured
  float factor;   // output-Hz multiplier that makes the dash read correctly
};

struct Settings {
  float hzPerMph   = DEF_HZ_PER_MPH;
  float noFixMph   = DEF_NO_FIX_MPH;
  float minMph     = DEF_MIN_MPH;
  float leadSec    = DEF_LEAD_SEC;
  float accelAlpha = DEF_ACCEL_ALPHA;
  bool  predictor  = true;
  uint8_t  gpsRateHz  = DEF_GPS_RATE_HZ;
  uint16_t bootWindowS = DEF_BOOT_WINDOW_S;
  char  apPass[33] = DEF_AP_PASS;
  uint8_t  calCount = 0;
  CalPoint cal[CAL_POINTS];
};

static Settings cfg;
static Preferences prefs;

static void settingsLoad() {
  prefs.begin("gpsspeed", true);
  cfg.hzPerMph    = prefs.getFloat("k", DEF_HZ_PER_MPH);
  cfg.noFixMph    = prefs.getFloat("nofix", DEF_NO_FIX_MPH);
  cfg.minMph      = prefs.getFloat("min", DEF_MIN_MPH);
  cfg.leadSec     = prefs.getFloat("lead", DEF_LEAD_SEC);
  cfg.accelAlpha  = prefs.getFloat("alpha", DEF_ACCEL_ALPHA);
  cfg.predictor   = prefs.getBool("pred", true);
  cfg.gpsRateHz   = prefs.getUChar("rate", DEF_GPS_RATE_HZ);
  cfg.bootWindowS = prefs.getUShort("win", DEF_BOOT_WINDOW_S);
  String pw = prefs.getString("pass", DEF_AP_PASS);
  strlcpy(cfg.apPass, pw.c_str(), sizeof(cfg.apPass));
  cfg.calCount = min<uint8_t>(prefs.getUChar("ncal", 0), CAL_POINTS);
  if (cfg.calCount) prefs.getBytes("cal", cfg.cal, sizeof(CalPoint) * cfg.calCount);
  prefs.end();

  // Never trust NVS blindly -- a bad value here drives the dash.
  if (!(cfg.hzPerMph > 1.0f && cfg.hzPerMph < 20.0f)) cfg.hzPerMph = DEF_HZ_PER_MPH;
  if (!(cfg.noFixMph >= 0.0f && cfg.noFixMph <= 30.0f)) cfg.noFixMph = DEF_NO_FIX_MPH;
  if (!(cfg.minMph >= 0.0f && cfg.minMph <= 5.0f)) cfg.minMph = DEF_MIN_MPH;
  if (!(cfg.leadSec >= 0.0f && cfg.leadSec <= 2.0f)) cfg.leadSec = DEF_LEAD_SEC;
  if (!(cfg.accelAlpha > 0.0f && cfg.accelAlpha <= 1.0f)) cfg.accelAlpha = DEF_ACCEL_ALPHA;
  if (cfg.gpsRateHz != 1 && cfg.gpsRateHz != 5 && cfg.gpsRateHz != 10) cfg.gpsRateHz = DEF_GPS_RATE_HZ;
  if (cfg.bootWindowS < 30 || cfg.bootWindowS > 3600) cfg.bootWindowS = DEF_BOOT_WINDOW_S;
  if (strlen(cfg.apPass) < 8) cfg.apPass[0] = 0;   // WPA2 needs 8+; anything shorter = open network
}

static void settingsSave() {
  prefs.begin("gpsspeed", false);
  prefs.putFloat("k", cfg.hzPerMph);
  prefs.putFloat("nofix", cfg.noFixMph);
  prefs.putFloat("min", cfg.minMph);
  prefs.putFloat("lead", cfg.leadSec);
  prefs.putFloat("alpha", cfg.accelAlpha);
  prefs.putBool("pred", cfg.predictor);
  prefs.putUChar("rate", cfg.gpsRateHz);
  prefs.putUShort("win", cfg.bootWindowS);
  prefs.putString("pass", cfg.apPass);
  prefs.putUChar("ncal", cfg.calCount);
  prefs.putBytes("cal", cfg.cal, sizeof(CalPoint) * CAL_POINTS);
  prefs.end();
}

static void settingsFactoryReset() {
  prefs.begin("gpsspeed", false);
  prefs.clear();
  prefs.end();
  cfg = Settings();
}
